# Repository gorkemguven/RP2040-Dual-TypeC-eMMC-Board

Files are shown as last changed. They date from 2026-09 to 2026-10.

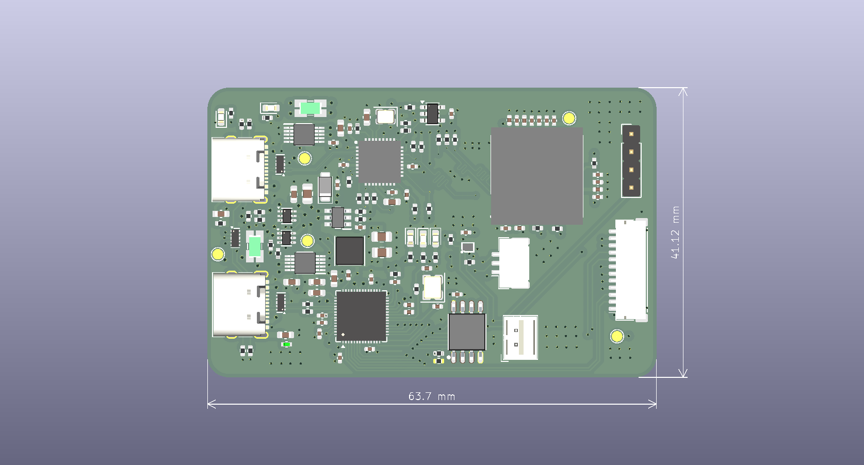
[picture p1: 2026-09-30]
KiCad Advanced Design a smart USB thumb drive_.png

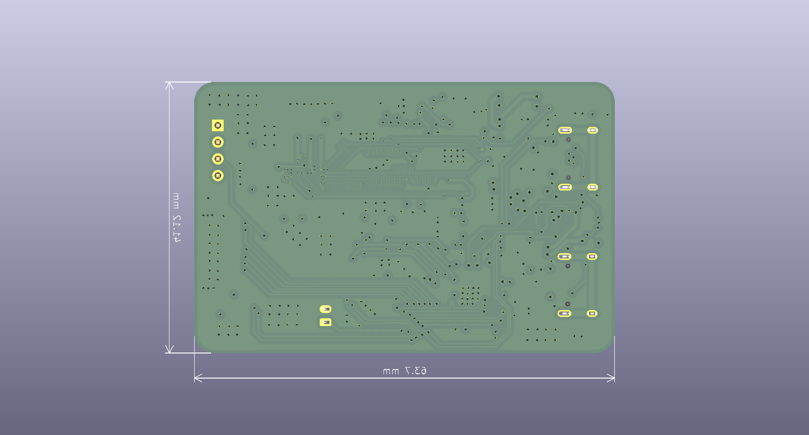
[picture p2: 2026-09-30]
KiCad Advanced Design a smart USB thumb drive.png

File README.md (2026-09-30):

# RP2040 Dual Type-C eMMC High-Speed Development & Telemetry Board (PicoVault)

Bu proje; **Raspberry Pi RP2040** çift çekirdekli mikrodenetleyicisi, **Microchip USB2244** yüksek hızlı USB 2.0 köprüsü ve **Micron eMMC (BGA-153)** yüksek yoğunluklu depolama birimini tek bir 4 katmanlı PCB üzerinde birleştiren endüstriyel standartta bir akıllı veri depolama ve geliştirme kartıdır.

Kart; çift USB Type-C mimarisi, donanımsal güç telemetrisi (çift INA226 akım/voltaj monitörü ve Kelvin algılama), yüksek doğruluklu sıcaklık izleme (TMP119) ve durum bilgilendirme OLED ekran arayüzü ile hem bağımsız bir yüksek hızlı USB flash sürücü hem de derinlemesine analiz yapabilen bir gömülü geliştirme platformu olarak tasarlanmıştır.

---

## 📌 Öne Çıkan Özellikler

* **Çift Çekirdekli İşlem Gücü:** Raspberry Pi RP2040 (Çift ARM Cortex-M0+ @ 133 MHz, 264 KB dahili SRAM).
* **Yüksek Hızlı Depolama (eMMC):** Micron BGA-153 paket yüksek hızlı eMMC bellek modülü.
* **Yüksek Hızlı USB Köprüsü:** Microchip USB2244 High-Speed USB 2.0 SD/eMMC kontrolcüsü (480 Mbps).
* **Boot Flash Belleği:** 128 Mb (16 MB) Winbond W25Q128JVSIC QSPI Flash[cite: 3].
* **Çift USB Type-C Portu:**
  * *Port 1 (Depolama):* USB2244 üzerinden doğrudan eMMC'ye yüksek hızlı USB 2.0 (480 Mbps) erişim.
  * *Port 2 (MCU / Telemetri):* RP2040 Full-Speed USB arayüzü (veri kaydı, programlama, seri haberleşme).
* **Donanımsal Güç ve Sıcaklık Telemetrisi:**
  * 2x **TI INA226** I2C güç/gerilim/akım izleme entegresi (2 mΩ 4-terminalli Kelvin şönt algılama)[cite: 7, 8].
  * 1x **TI TMP119** ±0.1°C yüksek hassasiyetli dijital sıcaklık sensörü[cite: 4].
  * 0.96'' I2C SSD1306 OLED ekran konnektörü ile anlık telemetri gösterimi[cite: 5].
* **Genişleme Portu:** Harici SPI, I2C, UART ve GPIO erişimi sağlayan 12-pin breakout soketi[cite: 1].
* **Üretim Optimizasyonu:** Maliyet düşürmek amacıyla tüm kritik bileşenler tek yüzeye (Single-Sided Assembly) yerleştirilmiştir.

---

## 📐 Donanım Mimarisi ve Yüksek Hızlı Sinyal Bütünlüğü

### 1. USB2244 – eMMC (BGA-153) 8-Bit Yüksek Hızlı Veri Yolu (Zero-Skew Matching)
USB2244 ile eMMC arasındaki 8-bit paralel veri yolu (MMC standardı), yüksek frekanslı çalışma modlarında saat ve veri gecikmelerini (skew) sıfırlamak için **tam 35.66 mm** boyuna meander teknikleriyle kusursuz şekilde eşitlenmiştir:
* **Tüm Hatların Uzunluğu:** Tam olarak **35.66 mm**
* **Maksimum Skew / Sapma:** **0.00 mm (0.00 ps)**
* **Hat Empedansı:** Katman 2 kesintisiz GND referansı üzerinden 50 Ω mikroşerit geometri.

| Sinyal Adı | Pin Adı | Rotalama Türü | Empedans | Net Hat Uzunluğu | Skew (Fark) |
| :--- | :--- | :--- | :---: | :---: | :---: |
| **`MMC_CLK`** | Clock (Saat) | GND Referanslı Mikroşerit | 50 Ω | **35.66 mm** | Referans |
| **`MMC_CMD`** | Command / Response | Çift Yönlü Kontrol | 50 Ω | **33.44 mm** | **2.22 mm** |
| **`MMCDA0`** | Data Bit 0 | Yüksek Hızlı Veri | 50 Ω | **35.66 mm** | **0.00 mm** |
| **`MMCDA1`** | Data Bit 1 | Yüksek Hızlı Veri | 50 Ω | **35.66 mm** | **0.00 mm** |
| **`MMCDA2`** | Data Bit 2 | Yüksek Hızlı Veri | 50 Ω | **35.66 mm** | **0.00 mm** |
| **`MMCDA3`** | Data Bit 3 | Yüksek Hızlı Veri | 50 Ω | **35.66 mm** | **0.00 mm** |
| **`MMCDA4`** | Data Bit 4 | Yüksek Hızlı Veri | 50 Ω | **35.56 mm** | **0.10 mm** |
| **`MMCDA5`** | Data Bit 5 | Yüksek Hızlı Veri | 50 Ω | **35.66 mm** | **0.00 mm** |
| **`MMCDA6`** | Data Bit 6 | Yüksek Hızlı Veri | 50 Ω | **35.66 mm** | **0.00 mm** |
| **`MMCDA7`** | Data Bit 7 | Yüksek Hızlı Veri | 50 Ω | **35.66 mm** | **0.00 mm** |
| **`MMC_RST_N`** | Hardware Reset | Filtrelenmiş Kontrol | 50 Ω | Bağımsız | Asenkron |

*(Not: Bu 10 hattın tamamında sıfır kör hat (stub-free) prensibi uygulanmış ve BGA çıkışlarında dönüş akımının bütünlüğü korunmuştur).*

### 2. QSPI Flash Yönlendirme ve Gecikme Eşleme (Length Matching)
Flash bellek yolu, 133 MHz saat hızında okuma/yazma kararlılığını garanti altına almak için 50 Ω kontrollü empedans ve katı boy eşleme kurallarıyla yönlendirilmiştir:
* **Tüm Sinyal Hatları:** Eşit parazitik yük için tam olarak **2 via** kullanılarak alt katmana geçirilmiştir.
* **Saat Hattı Referansı (`QSPI_SCLK`):** 24.54 mm
* **Veri Hatları Skew Dengesi:**
  * `QSPI_SD0`: 26.10 mm (ΔL = +1.56 mm)
  * `QSPI_SD1`: 25.76 mm (ΔL = +1.22 mm)
  * `QSPI_SD2`: 27.14 mm (ΔL = +2.60 mm)
  * `QSPI_SD3`: 24.81 mm (ΔL = +0.27 mm)
  * `QSPI_SS`: 22.57 mm (ΔL = -1.97 mm)
* **Stub İzolasyonu:** 1 kΩ (`R504`) BOOTSEL izolasyon direnci ve 10 kΩ (`R505`) pull-up direnci, yüksek hızlı `/CS` hattında açık devre yansıması oluşturmaması için doğrudan Flash entegresinin Pin 1 bacağının 1 mm yakınına konumlandırılmıştır[cite: 3].

### 3. Analog Kristal Osilatör Bölgesi (EMC & Noise Immunity)
* **Rezonatör:** RP2040 için 12 MHz SMD kristal ve 15 pF yük kapasitörleri.
* **Sönümleme:** `XOUT` bacağında 1 kΩ seri akım sınırlama/sönümleme direnci.
* **Gürültü Koruması (Keepout Area):** Kristalin ve yük kapasitörlerinin altındaki tüm katmanlar dijital sinyallerden arındırılmıştır[cite: 2]. `SPI_SCK` ve hızlı GPIO hatları kristal sınırının dışına taşınmış; Layer 2 üzerinde kesintisiz katı GND bakırı ve kristal gövde pinlerinde (Pin 2 ve 4) çift via topraklaması uygulanmıştır[cite: 2].

### 4. eMMC Güç Dağıtım Ağı (PDN - Decoupling Network)
* Tek yüzeyli montaj gereği dekuplaj kapasitörleri BGA-153 paketinin çevresine optimize mesafelerle dizilmiştir:
  * **VDDIM (`C2`):** 4.6 mm hat, 2 via, 100 nF + 1 µF çift filtreleme.
  * **VCC (`E6, F5` & `J10, K9`):** 100 nF, 1 µF ve 2.2 µF kapasitör grupları (6.5–8.0 mm).
  * **VCCQ (`C6` & `M4, N4, P3, P5`):** Çekirdek VCC hattındaki anahtarlama gürültüsünden etkilenmemesi için yüzeyde VCC'den izole edilmiş; ana +3.3V düzleminden yerel 2.2 µF kapasitörlerle beslenmiştir.

### 5. Kelvin Akım Algılama ve I2C Topolojisi
* **4-Wire Kelvin Sensing:** 2 mΩ şönt dirençlerin gerilim algılama pinleri (`IN+` ve `IN-`), yüksek akım taşıyan güç pedlerinden bağımsız olarak alt katmandan diferansiyel çift mantığıyla INA226 entegrelerine taşınmıştır[cite: 7, 9].
* **Adresleme:**
  * `IC702` (INA226 #1): A1 = GND, A0 = GND → **0x40**[cite: 8]
  * `IC703` (INA226 #2): A1 = GND, A0 = +3.3V → **0x41**[cite: 8]
* **I2C Veriyolu:** RP2040'tan çıkan tek veriyolu TMP119 (3.5 cm), OLED (5.3 cm), INA1 (7.0 cm) ve INA2 (8.8 cm) arayüzlerini beslemektedir[cite: 4, 5, 8]. Hat empedansı TMP119 yakınındaki 5 kΩ pull-up dirençleri (`R701`, `R702`) ile sürülmekte ve toplam veriyolu kapasitansı 400 pF standardının oldukça altında kalmaktadır[cite: 4, 6].

---

## 🔌 Bağlantı Portları ve Pin Şeması

### 1. J803 Genişleme Konnektörü (1x12 Pin Header)
Harici çevre birimleri ve geliştirme modülleri için dışarı çıkarılmış arayüzdür[cite: 1]:

| Pin | Sinyal Adı | Tip | Rotalama Detayı | Açıklama |
| :---: | :--- | :--- | :--- | :--- |
| **1** | `+3.3V` | Güç | Çift via ile +3.3V katmanına bağlı | Harici modül beslemesi |
| **2** | `UART_TX` | Çıkış | 50.00 mm (0 via) | Seri konsol / Debug çıkışı |
| **3** | `UART_RX` | Giriş | 49.80 mm (0 via) | Seri konsol giriş |
| **4** | `SPI_SCK` | Çıkış | 42.17 mm (2 via) | Harici SPI Saat hattı |
| **5** | `SPI_MOSI` | Çıkış | 41.52 mm (2 via) | Harici SPI Veri çıkışı |
| **6** | `SPI_MISO` | Giriş | 41.83 mm (2 via) | Harici SPI Veri girişi |
| **7** | `SPI_CS` | Çıkış | 41.92 mm (2 via) | Harici SPI Çip seçimi |
| **8** | `I2C_SDA` | Çift Yönlü | 57.08 mm (2 via) | Harici I2C Veri hattı |
| **9** | `I2C_SCL` | Çıkış | 56.62 mm (2 via) | Harici I2C Saat hattı |
| **10** | `GPIO14` | Giriş/Çıkış | 43.70 mm (2 via) | Genel amaçlı GPIO / Kesme |
| **11** | `GPIO15` | Giriş/Çıkış | 43.87 mm (2 via) | Genel amaçlı GPIO / Kesme |
| **12** | `GND` | Güç | Çift via ile ana GND katmanına bağlı | Ortak sistem toprağı |

*(Not: SPI veri yolu hatları arasındaki maksimum skew yalnızca 0.65 mm'dir; bu sayede yüksek hızlı SPI ekranlar veya harici modüllerle sorunsuz çalışır).*

### 2. Programlama ve Hata Ayıklama (Debug)
* **SWD Portu (`SWCLK`, `SWD`, `GND`):** Canlı hata ayıklama (step-by-step breakpoint debug) ve doğrudan bellek programlama arayüzüdür.
  * `SWCLK` (22.60 mm) ve `SWD` (23.00 mm) hatları tam simetrik ve 0.40 mm toleransla eşlenmiştir.
* **RUN (Donanımsal Reset):** 100 nF kapasitör ve 10 kΩ pull-up direnci ile çipin 3.66 mm dibinde filtrelenmiştir.
* **J502 (`USB_BOOT`):** 1 kΩ direnç üzerinden Flash `/CS` hattını toprağa çekerek RP2040'ı dahili ROM UF2 Mass Storage bootloader moduna geçirir[cite: 3].

---

## 🗂️ Depo Dosya Yapısı

```text
├── hardware/
│   ├── schematics/          # KiCad hiyerarşik şematik dosyaları (.kicad_sch)
│   ├── layout/              # KiCad 4-katman PCB yerleşim dosyaları (.kicad_pcb)
│   ├── libraries/           # Projeye özel kütüphane sembol ve ayak izleri (Footprints)
│   └── outputs/
│       ├── gerbers/         # Üretim için RS-274X Gerber ve Drill dosyaları
│       └── bom/             # Parça listesi (Bill of Materials - .csv)
├── docs/
│   ├── schematics.pdf       # Tek tıkla incelenebilir tam şematik PDF çıktısı
│   ├── 3d_renders/          # Kartın ön/arka 3D görsel renderları
│   └── datasheets/          # Kritik entegre dökümanları (USB2244, INA226, TMP119, W25Q128)
├── .gitignore               # KiCad geçici ve yedek dosyalarını filtreler
└── README.md                # Proje dokümantasyonu

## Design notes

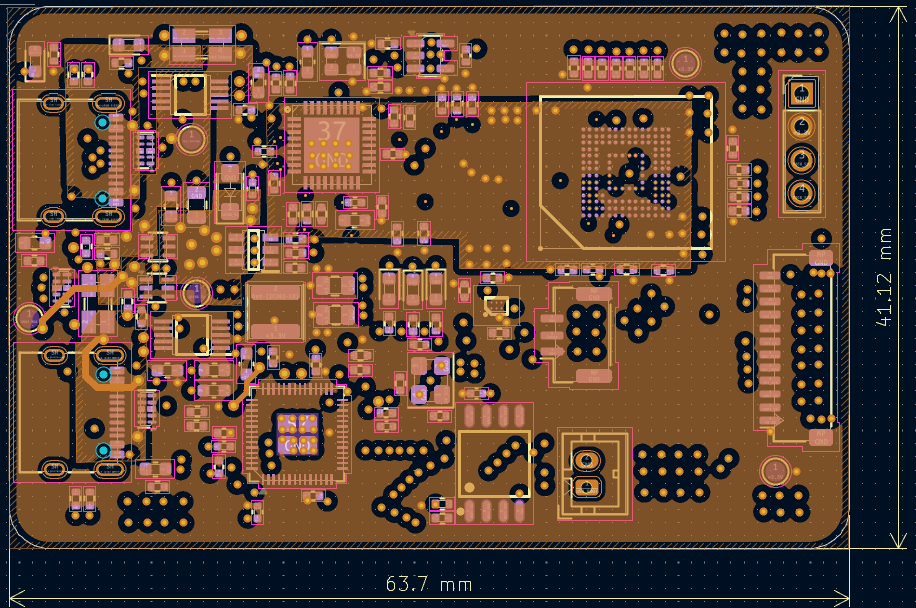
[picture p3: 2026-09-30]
akıllı_usb_bellek_layer_3.png

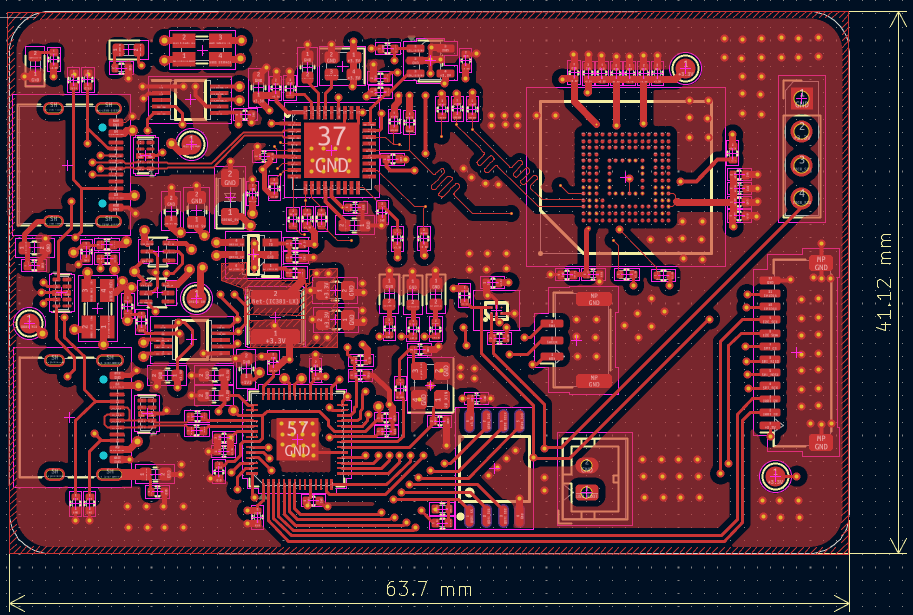
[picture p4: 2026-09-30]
akıllı_usb_bellek_layer_1.png

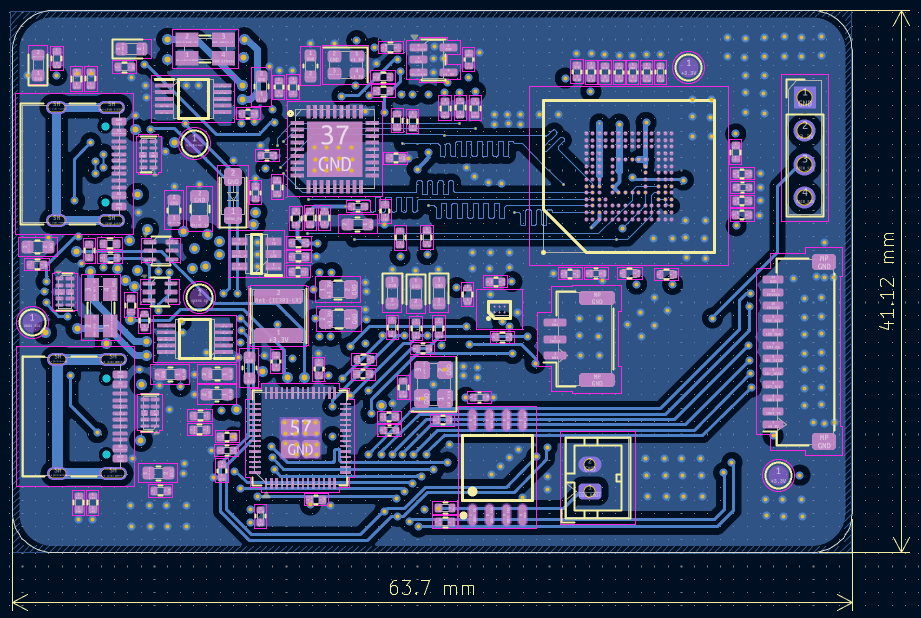
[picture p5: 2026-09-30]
akıllı_usb_bellek_layer_4.png

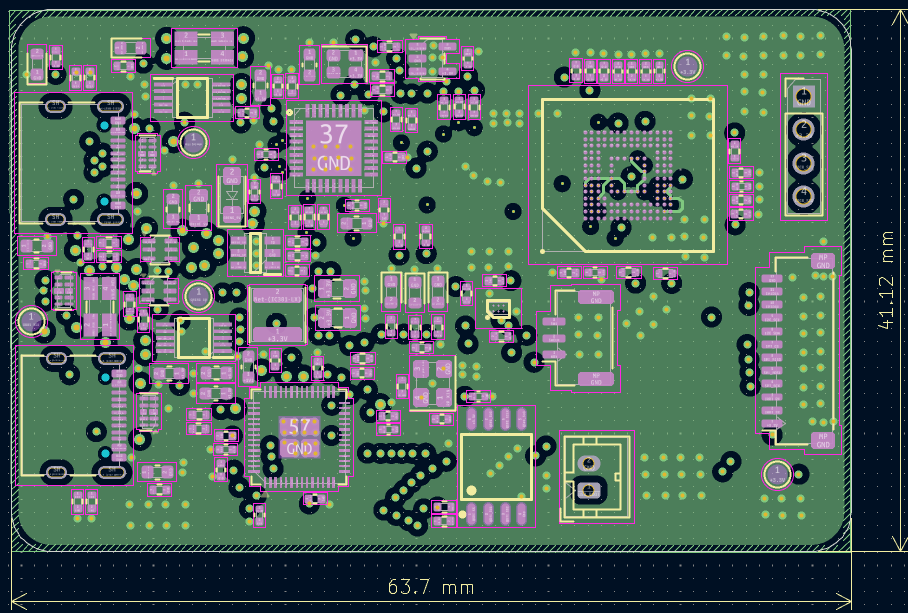
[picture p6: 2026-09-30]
akıllı_usb_bellek_layer_2.png

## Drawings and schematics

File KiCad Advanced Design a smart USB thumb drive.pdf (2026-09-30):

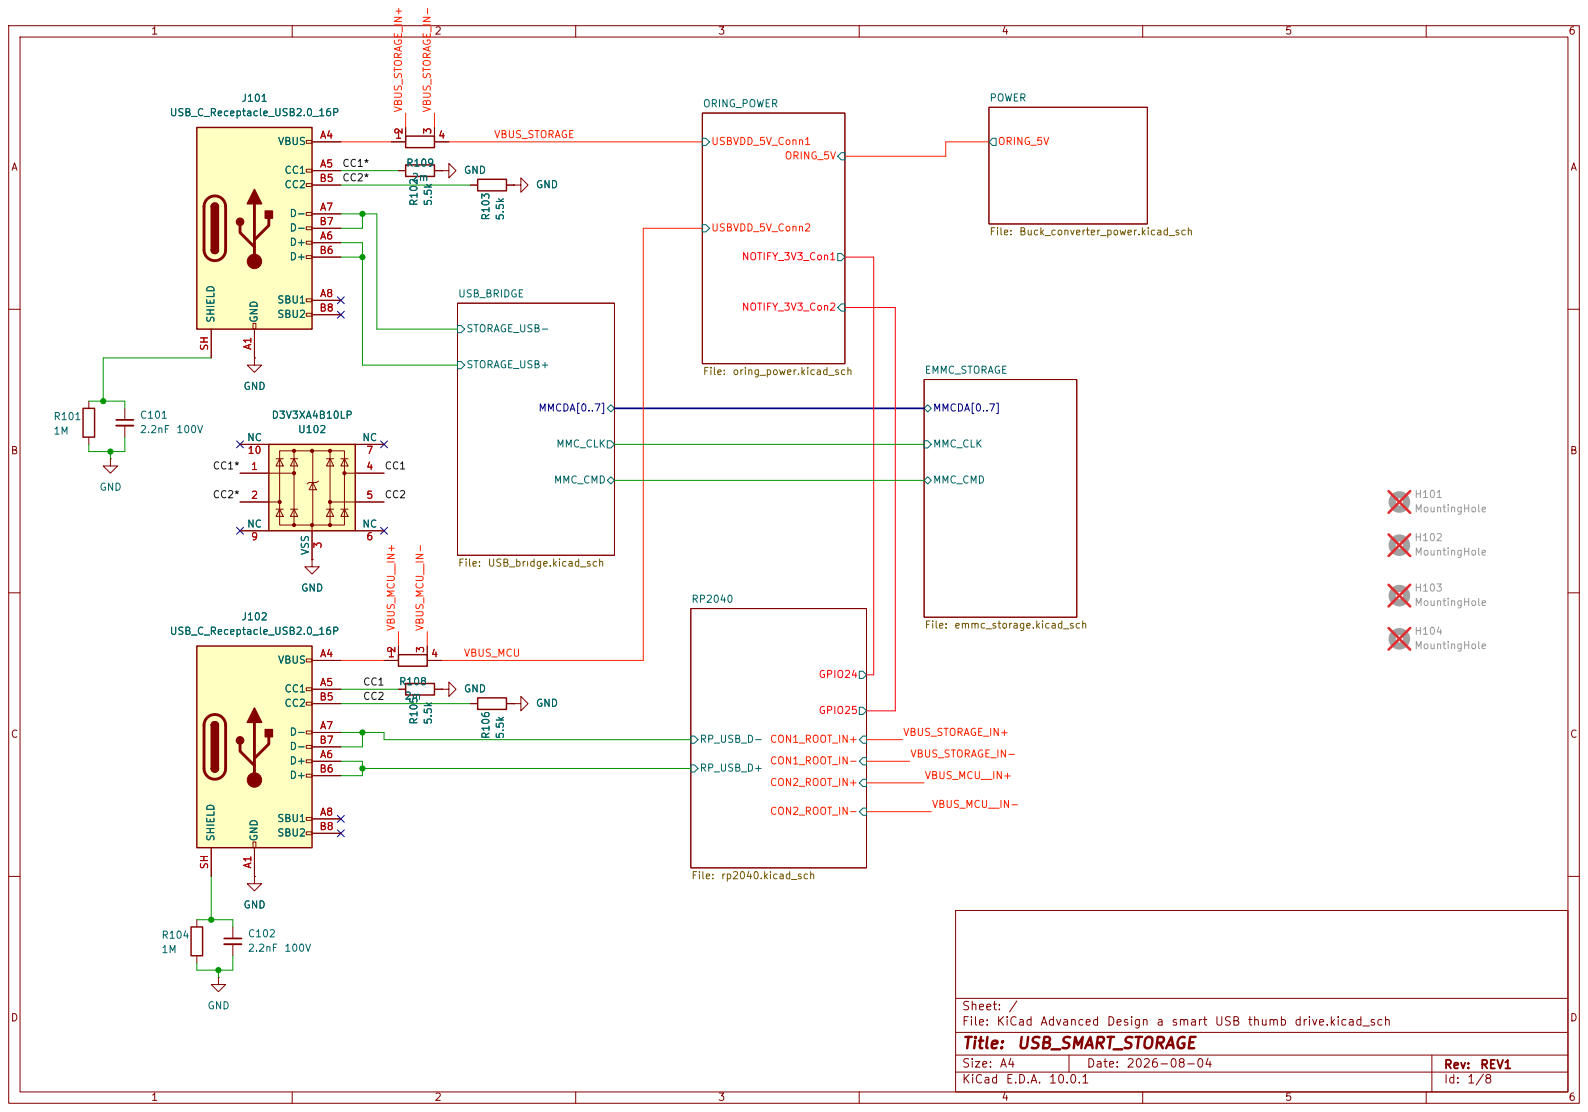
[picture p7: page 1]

Sheet: /
File: KiCad Advanced Design a smart USB thumb drive.kicad_sch
Title: USB_SMART_STORAGE

Size: A4 | Rev: REV1
KiCad E.D.A. 10.0.1 | Id: 1/8

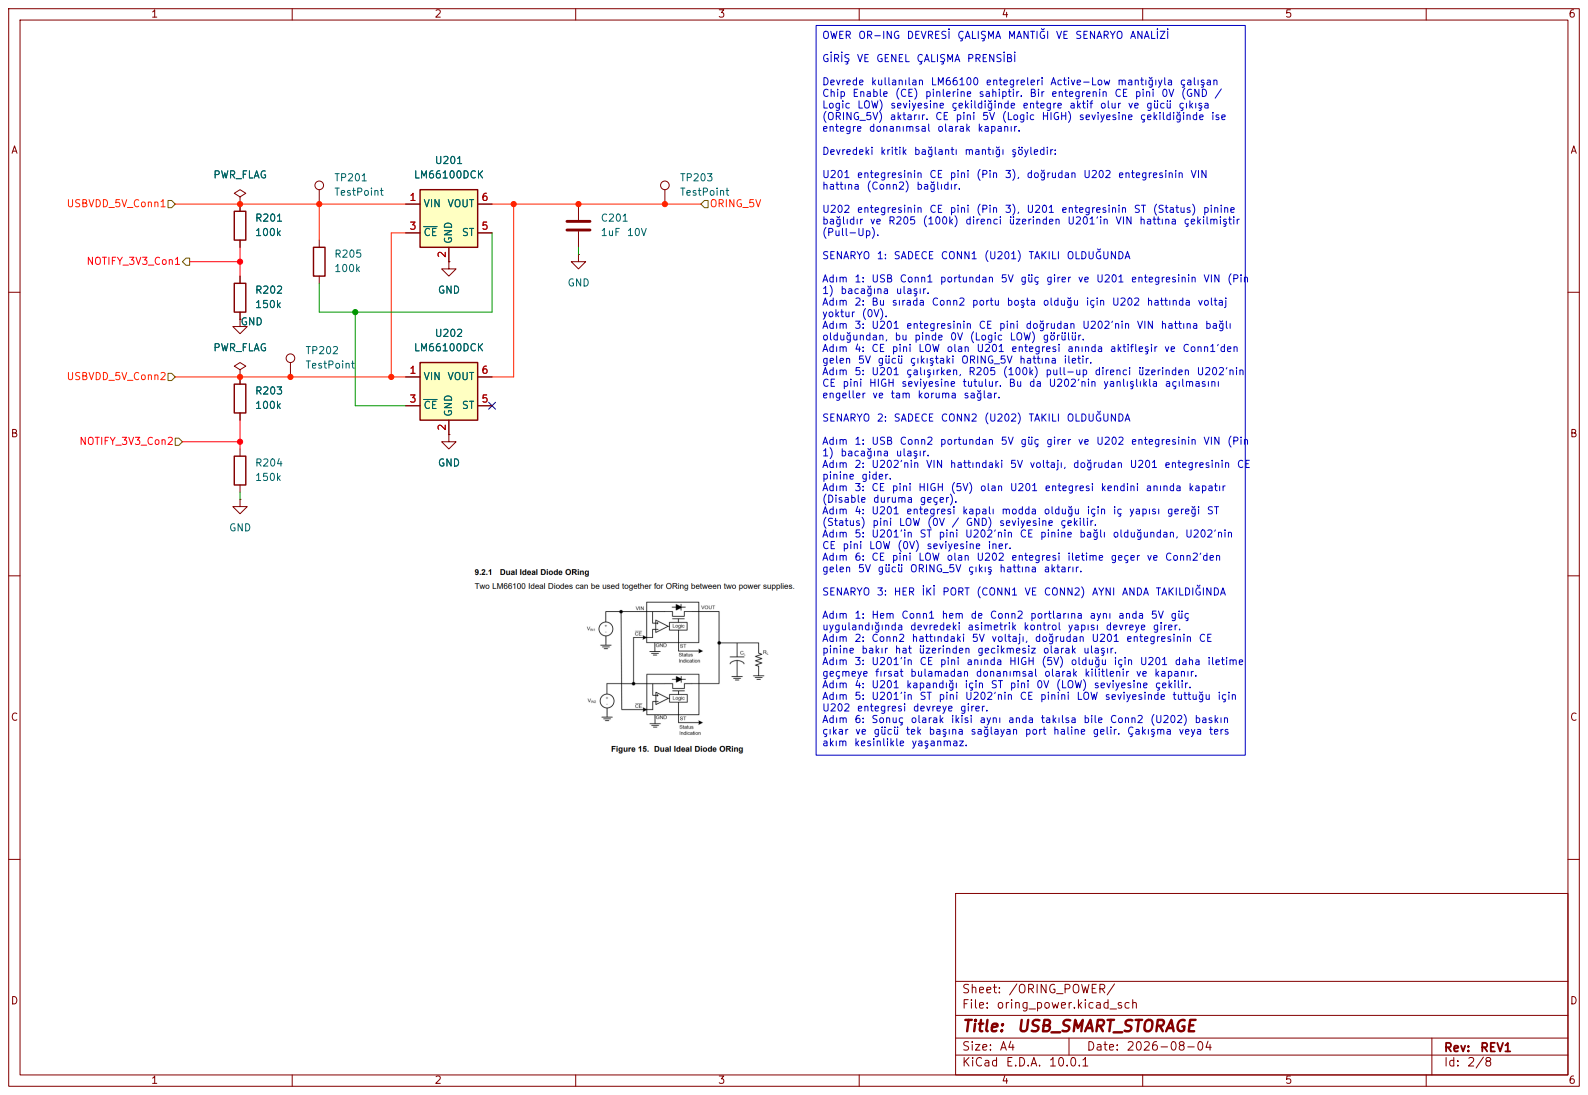
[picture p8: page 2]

GİRİŞ VE GENEL ÇALIŞMA PRENSİBİ Devrede kullanılan LM66100 entegreleri Active-Low mantığıyla çalışan

Chip Enable (CE) pinlerine sahiptir. Bir entegrenin CE pini 0V (GND /
Logic LOW) seviyesine çekildiğinde entegre aktif olur ve gücü çıkışa
(ORING_5V) aktarır. CE pini 5V (Logic HIGH) seviyesine çekildiğinde ise
entegre donanımsal olarak kapanır. Devredeki kritik bağlantı mantığı şöyledir: U201 entegresinin CE pini (Pin 3), doğrudan U202 entegresinin VIN

hattına (Conn2) bağlıdır. U202 entegresinin CE pini (Pin 3), U201 entegresinin ST (Status) pinine

bağlıdır ve R205 (100k) direnci üzerinden U201'in VIN hattına çekilmiştir
(Pull-Up). SENARYO 1: SADECE CONN1 (U201) TAKILI OLDUĞUNDA

Adım 1: USB Conn1 portundan 5V güç girer ve U201 entegresinin VIN (Pin 1) bacağına ulaşır. Adım 2: Bu sırada Conn2 portu boşta olduğu için U202 hattında voltaj

yoktur (0V). Adım 3: U201 entegresinin CE pini doğrudan U202'nin VIN hattına bağlı

olduğundan, bu pinde 0V (Logic LOW) görülür. Adım 4: CE pini LOW olan U201 entegresi anında aktifleşir ve Conn1'den

gelen 5V gücü çıkıştaki ORING_5V hattına iletir. Adım 5: U201 çalışırken, R205 (100k) pull-up direnci üzerinden U202'nin CE pini HIGH seviyesine tutulur. Bu da U202'nin yanlışlıkla açılmasını

engeller ve tam koruma sağlar. SENARYO 2: SADECE CONN2 (U202) TAKILI OLDUĞUNDA

Adım 1: USB Conn2 portundan 5V güç girer ve U202 entegresinin VIN (Pin 1) bacağına ulaşır. Adım 2: U202'nin VIN hattındaki 5V voltajı, doğrudan U201 entegresinin CE

pinine gider. Adım 3: CE pini HIGH (5V) olan U201 entegresi kendini anında kapatır

(Disable duruma geçer). Adım 4: U201 entegresi kapalı modda olduğu için iç yapısı gereği ST

(Status) pini LOW (0V / GND) seviyesine çekilir. Adım 5: U201'in ST pini U202'nin CE pinine bağlı olduğundan, U202'nin CE pini LOW (0V) seviyesine iner. Adım 6: CE pini LOW olan U202 entegresi iletime geçer ve Conn2'den

gelen 5V gücü ORING_5V çıkış hattına aktarır. SENARYO 3: HER İKİ PORT (CONN1 VE CONN2) AYNI ANDA TAKILDIĞINDA

Adım 1: Hem Conn1 hem de Conn2 portlarına aynı anda 5V güç
uygulandığında devredeki asimetrik kontrol yapısı devreye girer. Adım 2: Conn2 hattındaki 5V voltajı, doğrudan U201 entegresinin CE

pinine bakır hat üzerinden gecikmesiz olarak ulaşır. Adım 3: U201'in CE pini anında HIGH (5V) olduğu için U201 daha iletime geçmeye fırsat bulamadan donanımsal olarak kilitlenir ve kapanır. Adım 4: U201 kapandığı için ST pini 0V (LOW) seviyesine çekilir. Adım 5: U201'in ST pini U202'nin CE pinini LOW seviyesinde tuttuğu için U202 entegresi devreye girer. Adım 6: Sonuç olarak ikisi aynı anda takılsa bile Conn2 (U202) baskın

çıkar ve gücü tek başına sağlayan port haline gelir. Çakışma veya ters akım kesinlikle yaşanmaz.

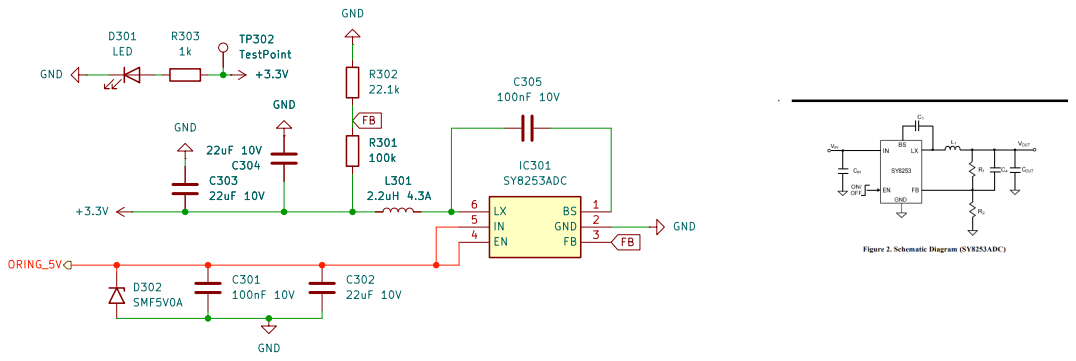
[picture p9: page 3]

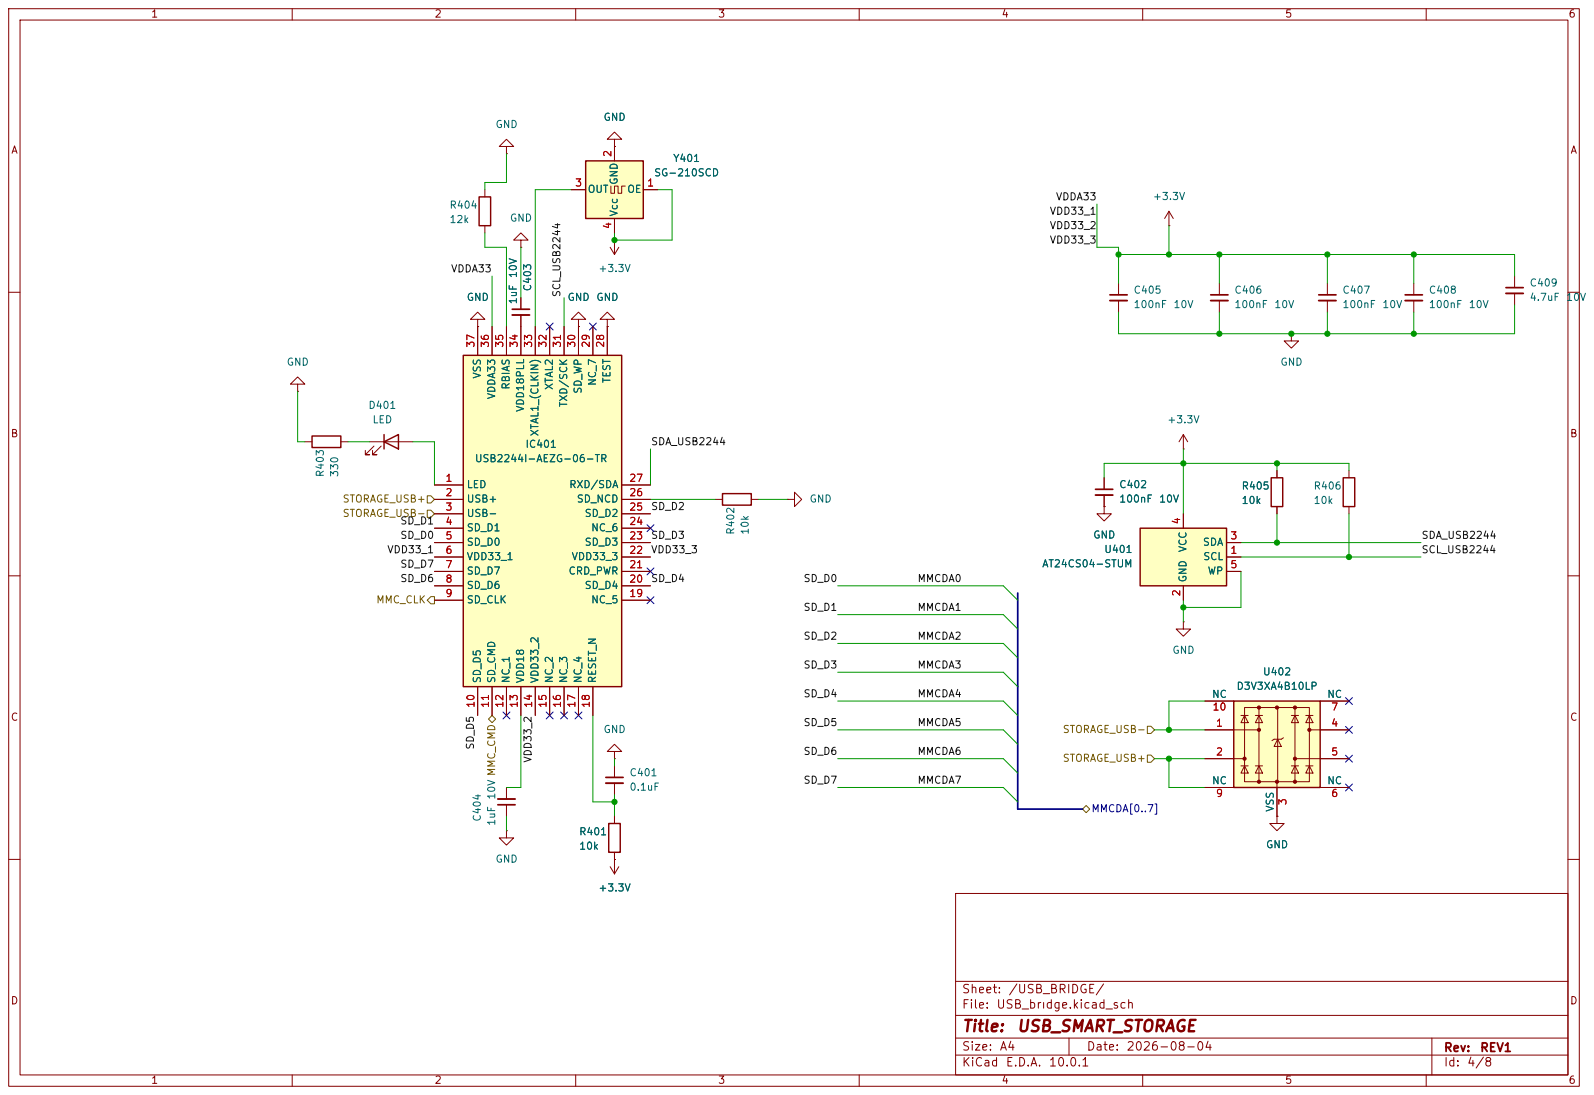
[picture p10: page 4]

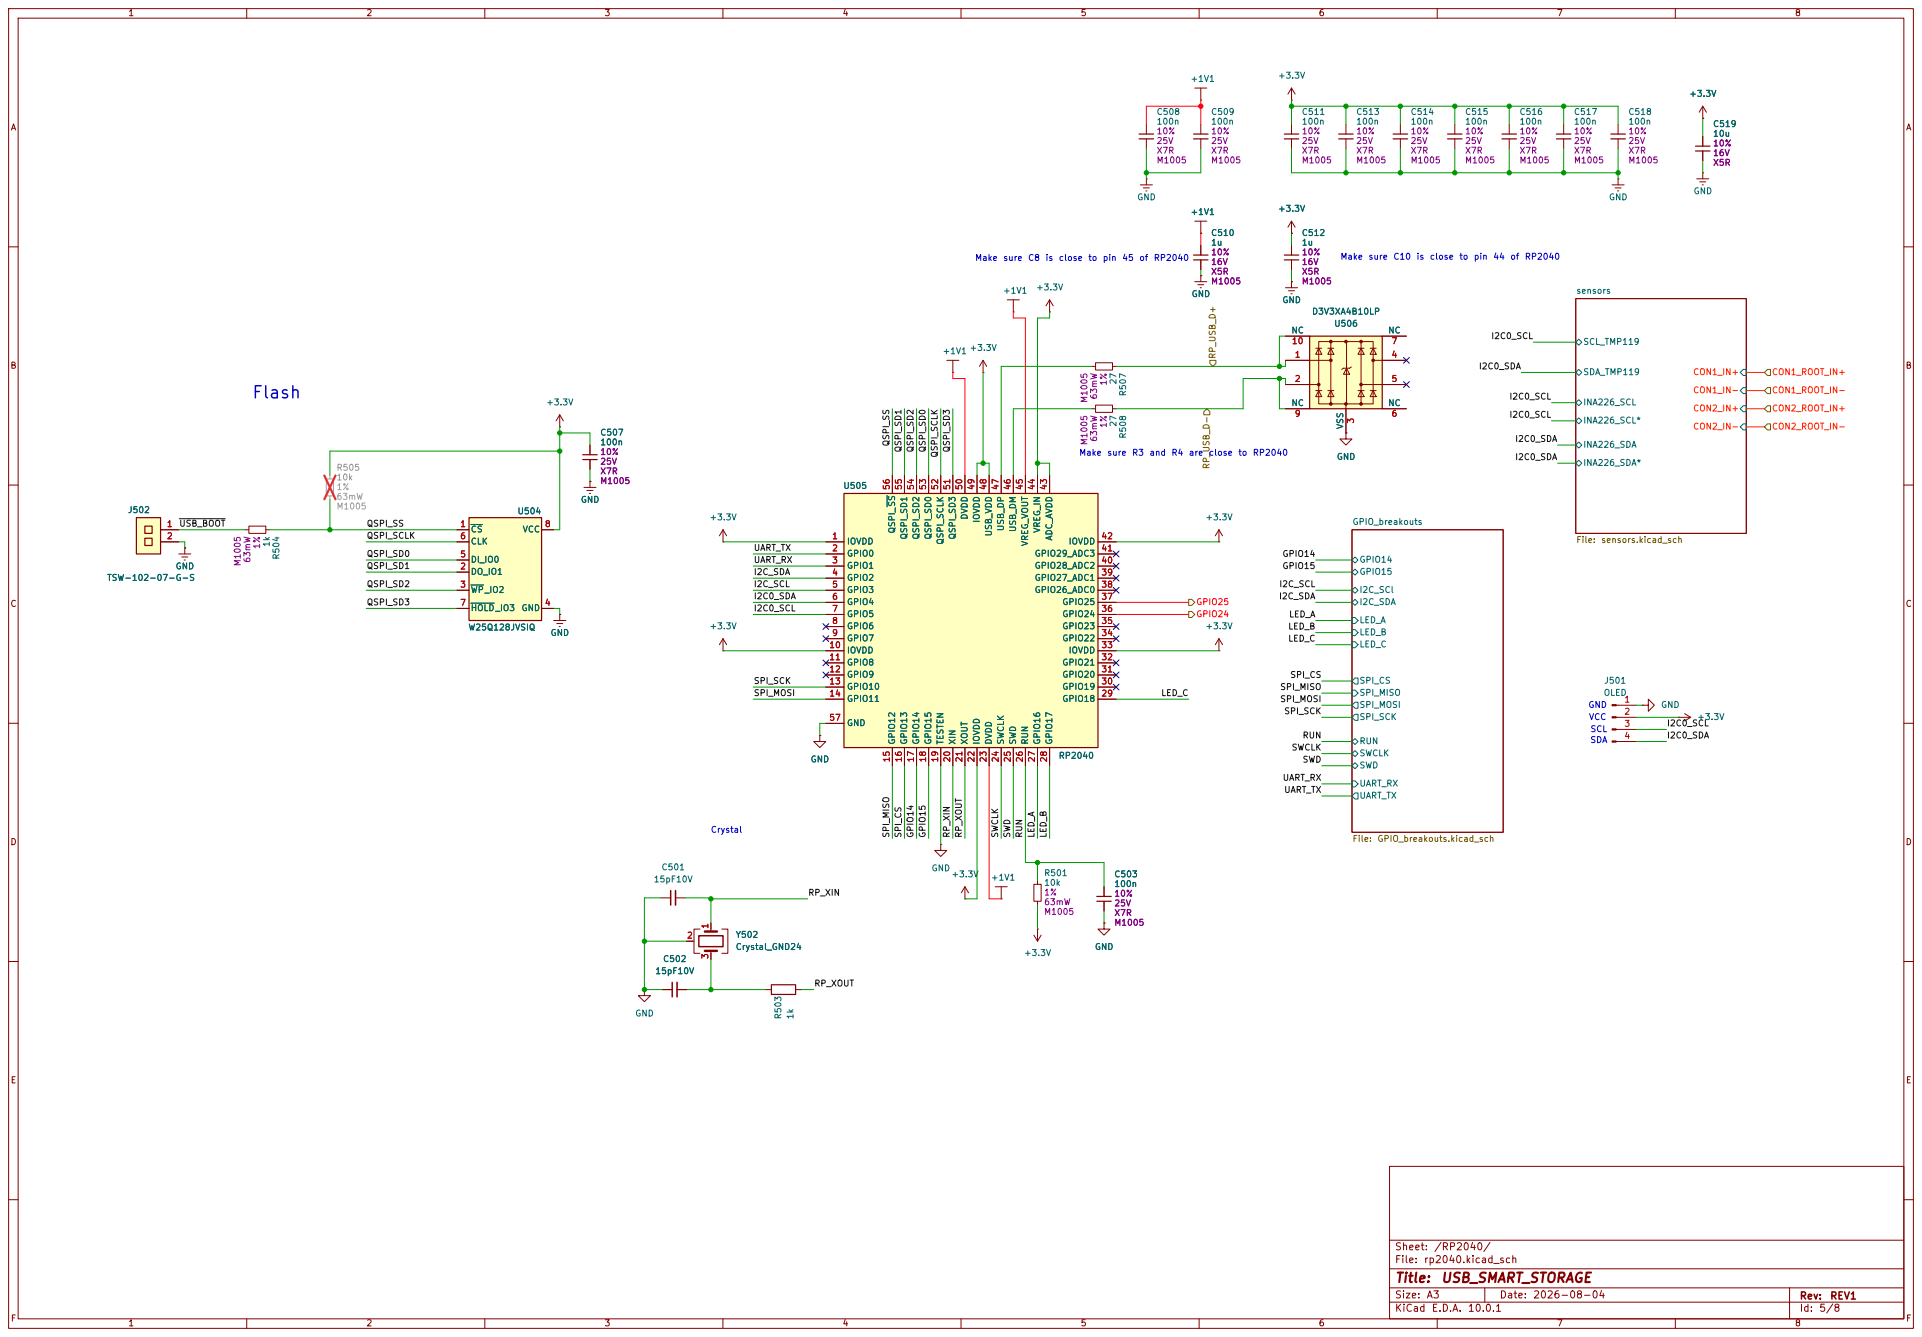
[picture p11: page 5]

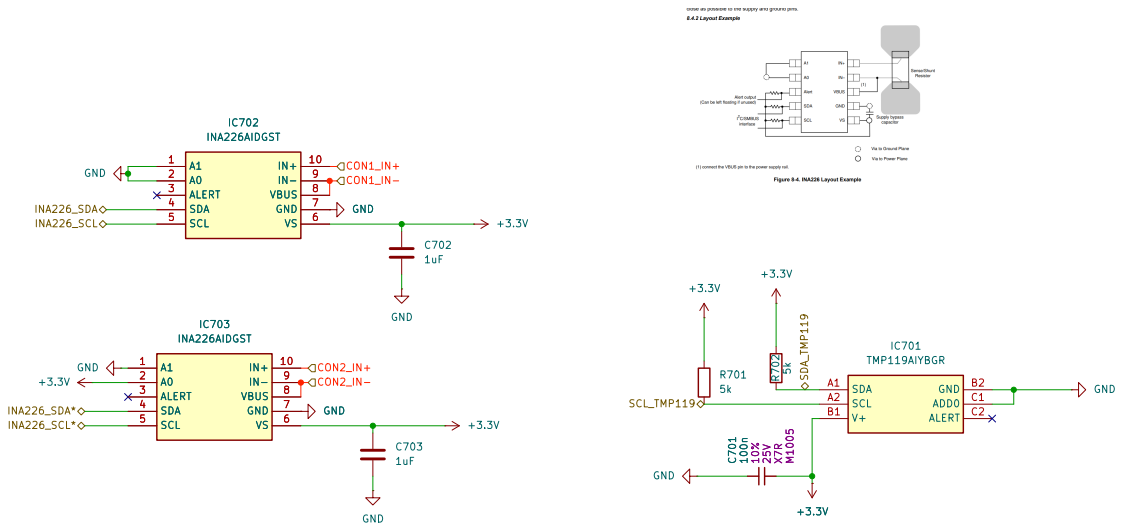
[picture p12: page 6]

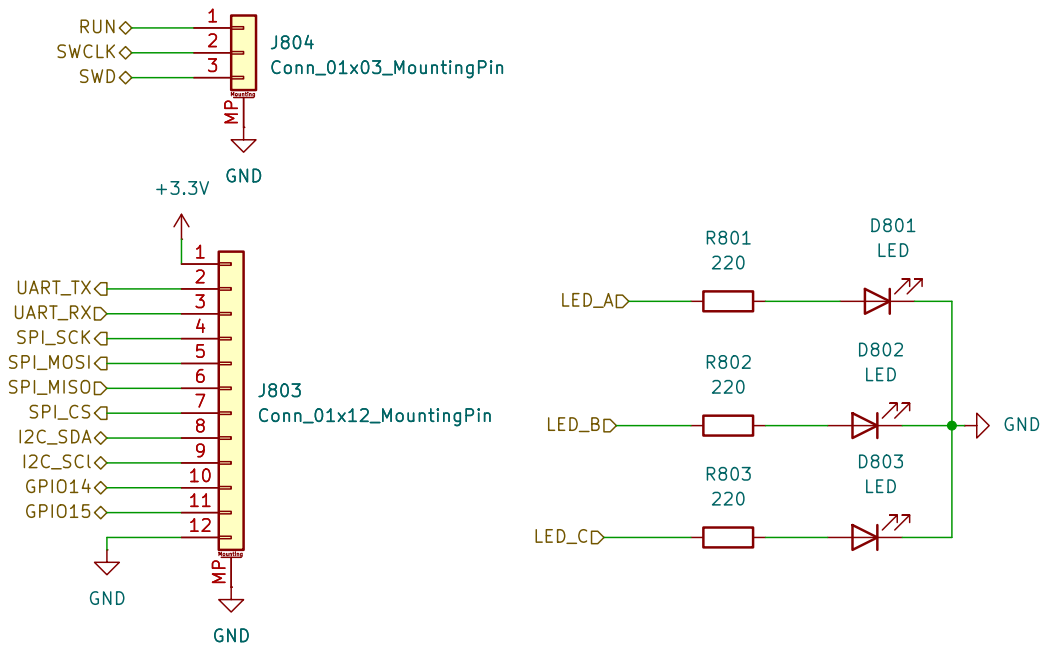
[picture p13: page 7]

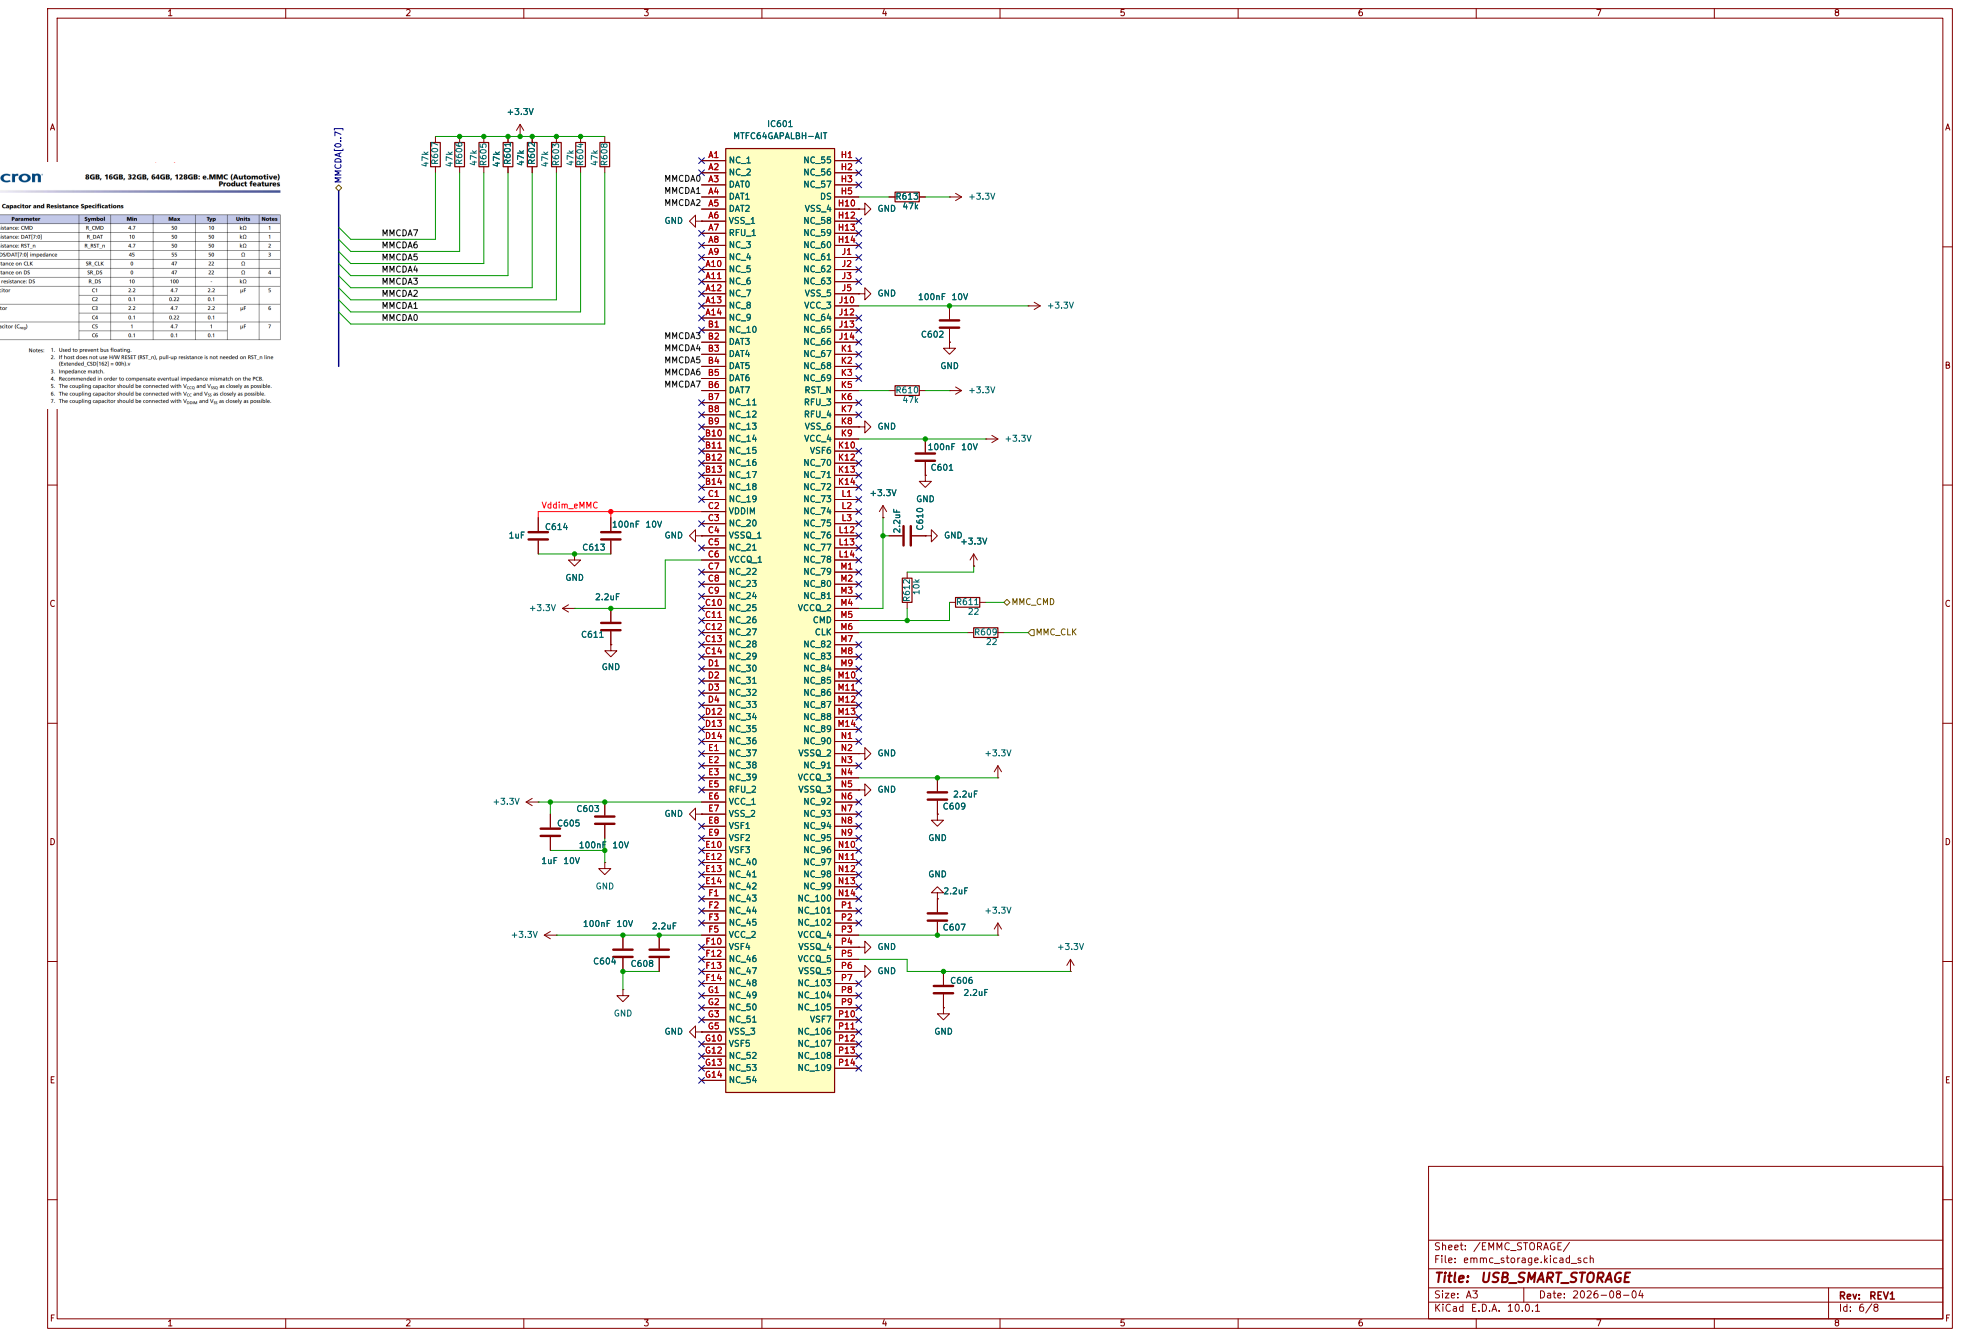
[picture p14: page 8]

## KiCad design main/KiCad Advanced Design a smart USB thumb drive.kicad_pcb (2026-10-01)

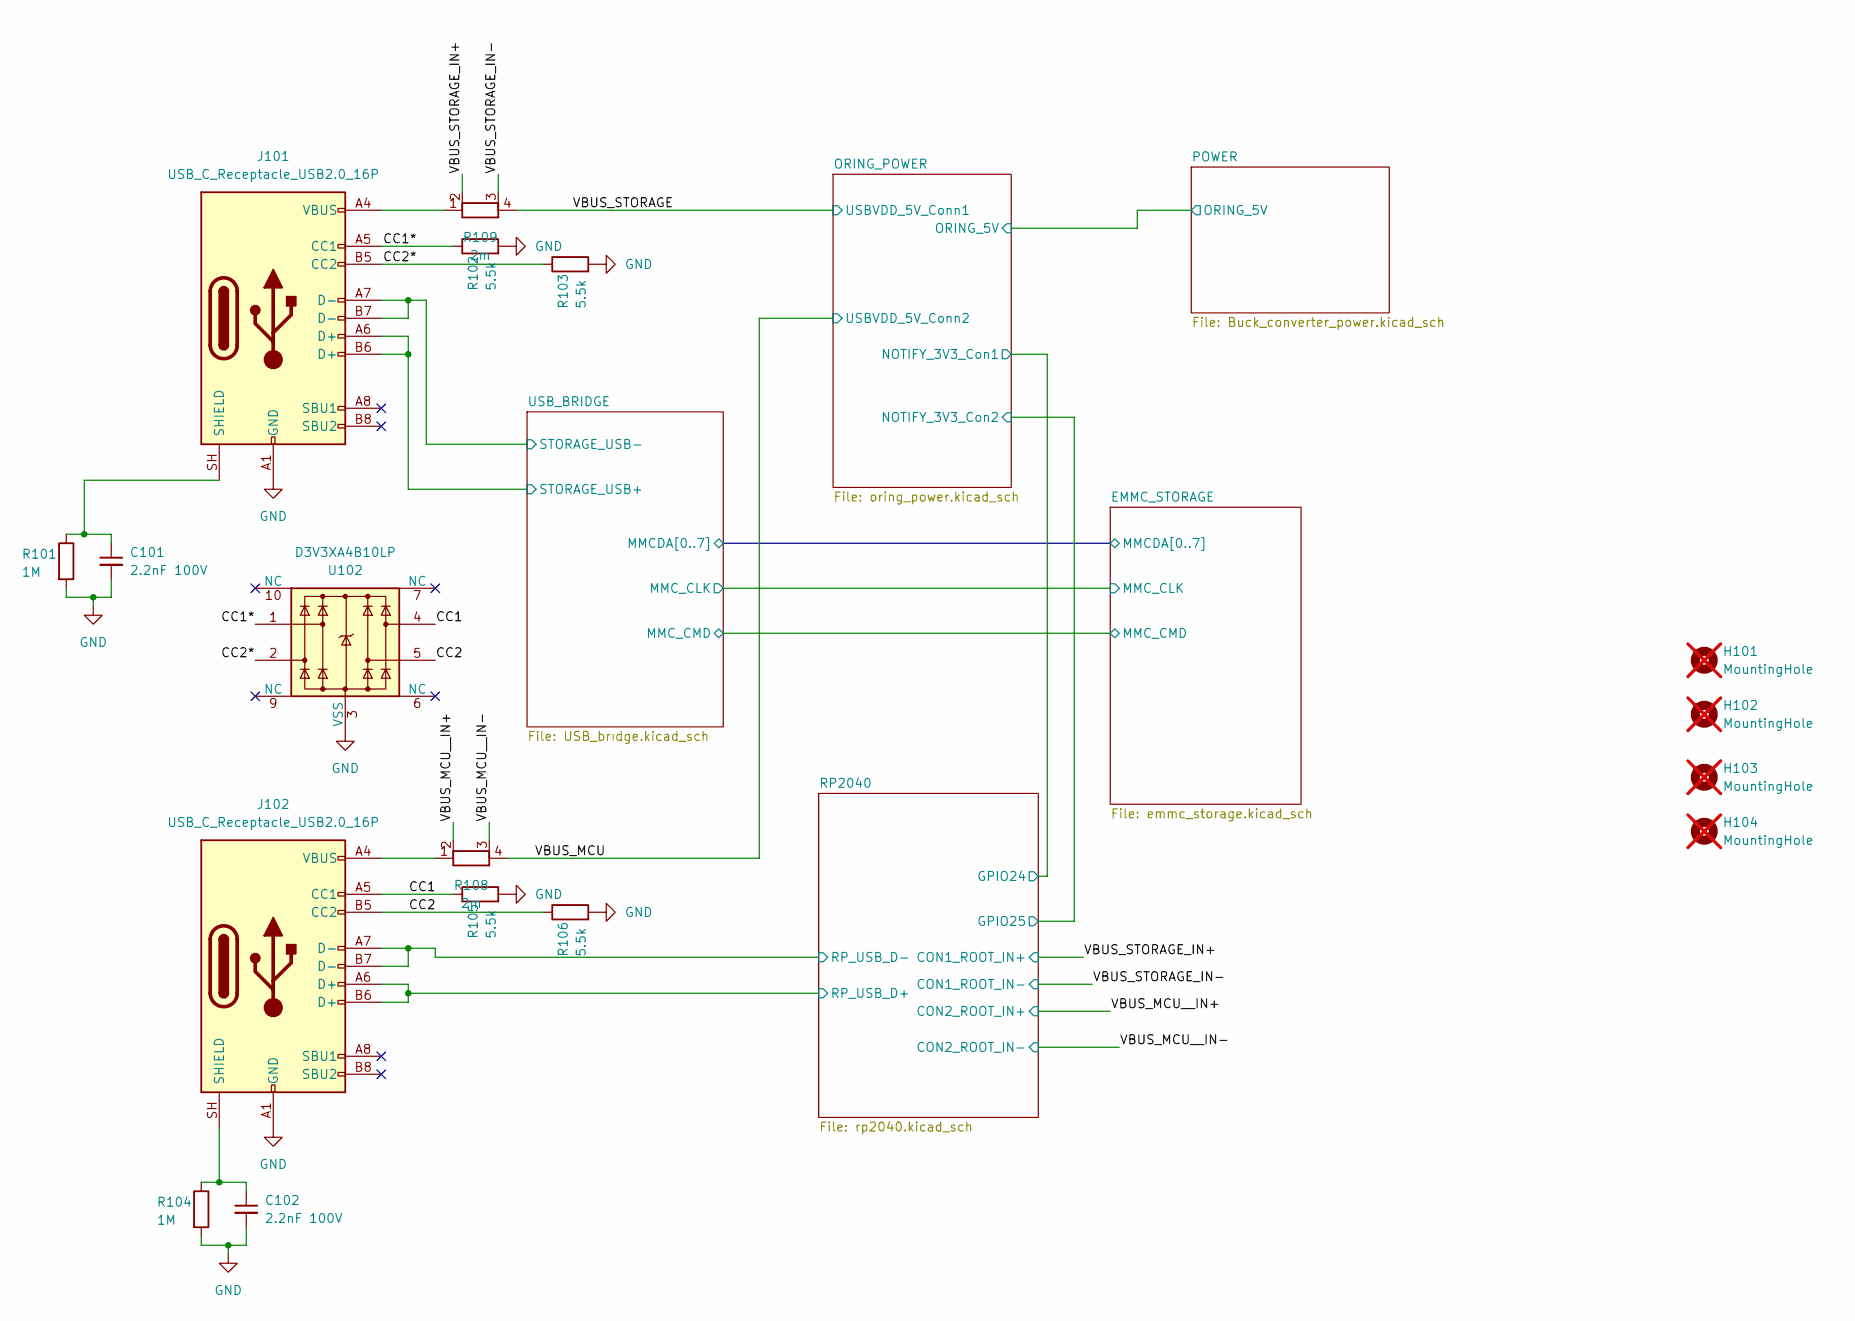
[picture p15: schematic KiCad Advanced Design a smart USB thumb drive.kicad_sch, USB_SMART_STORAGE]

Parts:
C101, C102: 2.2nF 100V; C_0603_1608Metric
H101, H102, H103, H104: MountingHole; MountingHole_2.2mm_M2; not fitted
J101, J102: USB_C_Receptacle_USB2.0_16P; USB_C_Receptacle_XKB_U262-16XN-4BVC11
R101, R104: 1M; R_0402_1005Metric
R102, R103, R105, R106: 5.5k; R_0402_1005Metric
R108, R109: 2m; R_Shunt_Ohmite_LVK12
U102: D3V3XA4B10LP; Diodes_UDFN-10_1x2.5mm_P0.5mm

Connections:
/CC1: J102.A5 (CC1), R105.1, U102.4
/CC1*: J101.A5 (CC1), R102.1, U102.1
/CC2: J102.B5 (CC2), R106.1, U102.5
/CC2*: J101.B5 (CC2), R103.1, U102.2
/RP2040/RP_USB_D+: J102.A6 (D+), J102.B6 (D+); also elsewhere on the board
/RP2040/RP_USB_D-: J102.A7 (D-), J102.B7 (D-); also elsewhere on the board
/USB_BRIDGE/STORAGE_USB+: J101.A6 (D+), J101.B6 (D+); also elsewhere on the board
/USB_BRIDGE/STORAGE_USB-: J101.A7 (D-), J101.B7 (D-); also elsewhere on the board
/VBUS_MCU: R108.4; also elsewhere on the board
/VBUS_MCU__IN+: R108.2; also elsewhere on the board
/VBUS_MCU__IN-: R108.3; also elsewhere on the board
/VBUS_STORAGE: R109.4; also elsewhere on the board
/VBUS_STORAGE_IN+: R109.2; also elsewhere on the board
/VBUS_STORAGE_IN-: R109.3; also elsewhere on the board
GND: C101.2, C102.2, J101.A1 (GND), J101.A12 (GND), J101.B1 (GND), J101.B12 (GND), J102.A1 (GND), J102.A12 (GND), J102.B1 (GND), J102.B12 (GND), R101.2, R102.2, R103.2, R104.2, R105.2, R106.2, U102.3 (VSS), U102.8 (VSS); also elsewhere on the board
unnamed: C101.1, J101.SH (SHIELD), R101.1
unnamed: J101.A4 (VBUS), J101.A9 (VBUS), J101.B4 (VBUS), J101.B9 (VBUS), R109.1
unnamed: C102.1, J102.SH (SHIELD), R104.1
unnamed: J102.A4 (VBUS), J102.A9 (VBUS), J102.B4 (VBUS), J102.B9 (VBUS), R108.1

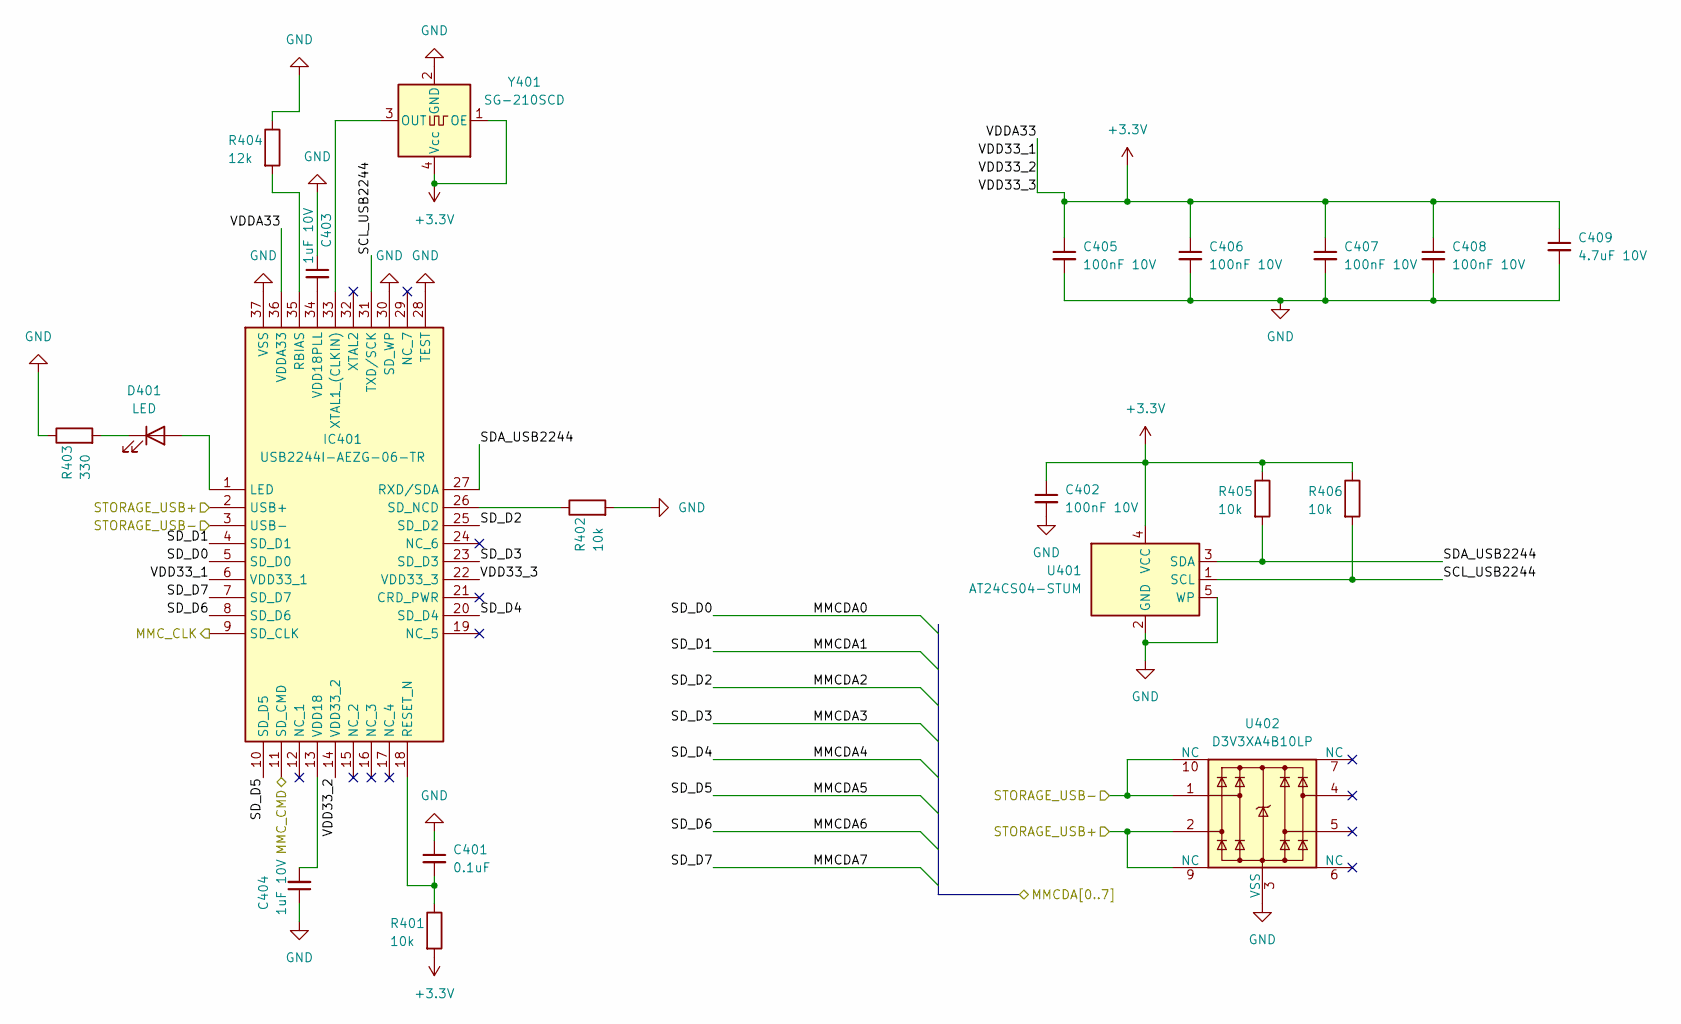
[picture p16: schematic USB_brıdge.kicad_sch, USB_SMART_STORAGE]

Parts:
C401: 0.1uF; C_0402_1005Metric
C402, C405, C406, C407, C408: 100nF 10V; C_0402_1005Metric
C403, C404: 1uF 10V; C_0603_1608Metric
C409: 4.7uF 10V; C_0603_1608Metric
D401: LED; LED_0603_1608Metric
IC401: USB2244I-AEZG-06-TR; QFN50P600X600X90-37N-D; Manufacturer_Part_Number USB2244I-AEZG-06-TR; Mouser Part Number 579-USB2244IAEZG06TR
R401, R402, R405, R406: 10k; R_0402_1005Metric
R403: 330; R_0402_1005Metric
R404: 12k; R_0402_1005Metric
U401: AT24CS04-STUM; SOT-23-5
U402: D3V3XA4B10LP; Diodes_UDFN-10_1x2.5mm_P0.5mm
Y401: SG-210SCD; Oscillator_SMD_SeikoEpson_SG210-4Pin_2.5x2.0mm

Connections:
+3.3V: C402.1, C405.1, C406.1, C407.1, C408.1, C409.1, IC401.6 (VDD33_1), IC401.14 (VDD33_2), IC401.22 (VDD33_3), IC401.36 (VDDA33), R401.2, R405.1, R406.1, U401.4 (VCC), Y401.1 (OE), Y401.4 (Vcc); also elsewhere on the board
/EMMC_STORAGE/MMCDA0: IC401.5 (SD_D0); also elsewhere on the board
/EMMC_STORAGE/MMCDA1: IC401.4 (SD_D1); also elsewhere on the board
/EMMC_STORAGE/MMCDA2: IC401.25 (SD_D2); also elsewhere on the board
/EMMC_STORAGE/MMCDA3: IC401.23 (SD_D3); also elsewhere on the board
/EMMC_STORAGE/MMCDA4: IC401.20 (SD_D4); also elsewhere on the board
/EMMC_STORAGE/MMCDA5: IC401.10 (SD_D5); also elsewhere on the board
/EMMC_STORAGE/MMCDA6: IC401.8 (SD_D6); also elsewhere on the board
/EMMC_STORAGE/MMCDA7: IC401.7 (SD_D7); also elsewhere on the board
/EMMC_STORAGE/MMC_CLK: IC401.9 (SD_CLK); also elsewhere on the board
/EMMC_STORAGE/MMC_CMD: IC401.11 (SD_CMD); also elsewhere on the board
/USB_BRIDGE/SCL_USB2244: IC401.31 (TXD/SCK), R406.2, U401.1 (SCL)
/USB_BRIDGE/SDA_USB2244: IC401.27 (RXD/SDA), R405.2, U401.3 (SDA)
/USB_BRIDGE/STORAGE_USB+: IC401.2 (USB+), U402.2, U402.9 (NC); also elsewhere on the board
/USB_BRIDGE/STORAGE_USB-: IC401.3 (USB-), U402.1, U402.10 (NC); also elsewhere on the board
GND: C401.1, C402.2, C403.1, C404.1, C405.2, C406.2, C407.2, C408.2, C409.2, IC401.28 (TEST), IC401.30 (SD_WP), IC401.37 (VSS), R402.2, R403.1, R404.1, U401.2 (GND), U401.5 (WP), U402.3 (VSS), U402.8 (VSS), Y401.2 (GND); also elsewhere on the board
unnamed: D401.2 (A), IC401.1 (LED)
unnamed: D401.1 (K), R403.2
unnamed: IC401.35 (RBIAS), R404.2
unnamed: C401.2, IC401.18 (RESET_N), R401.1
unnamed: IC401.26 (SD_NCD), R402.1
unnamed: C404.2, IC401.13 (VDD18)
unnamed: C403.2, IC401.34 (VDD18PLL)
unnamed: IC401.33 (XTAL1_(CLKIN)), Y401.3 (OUT)

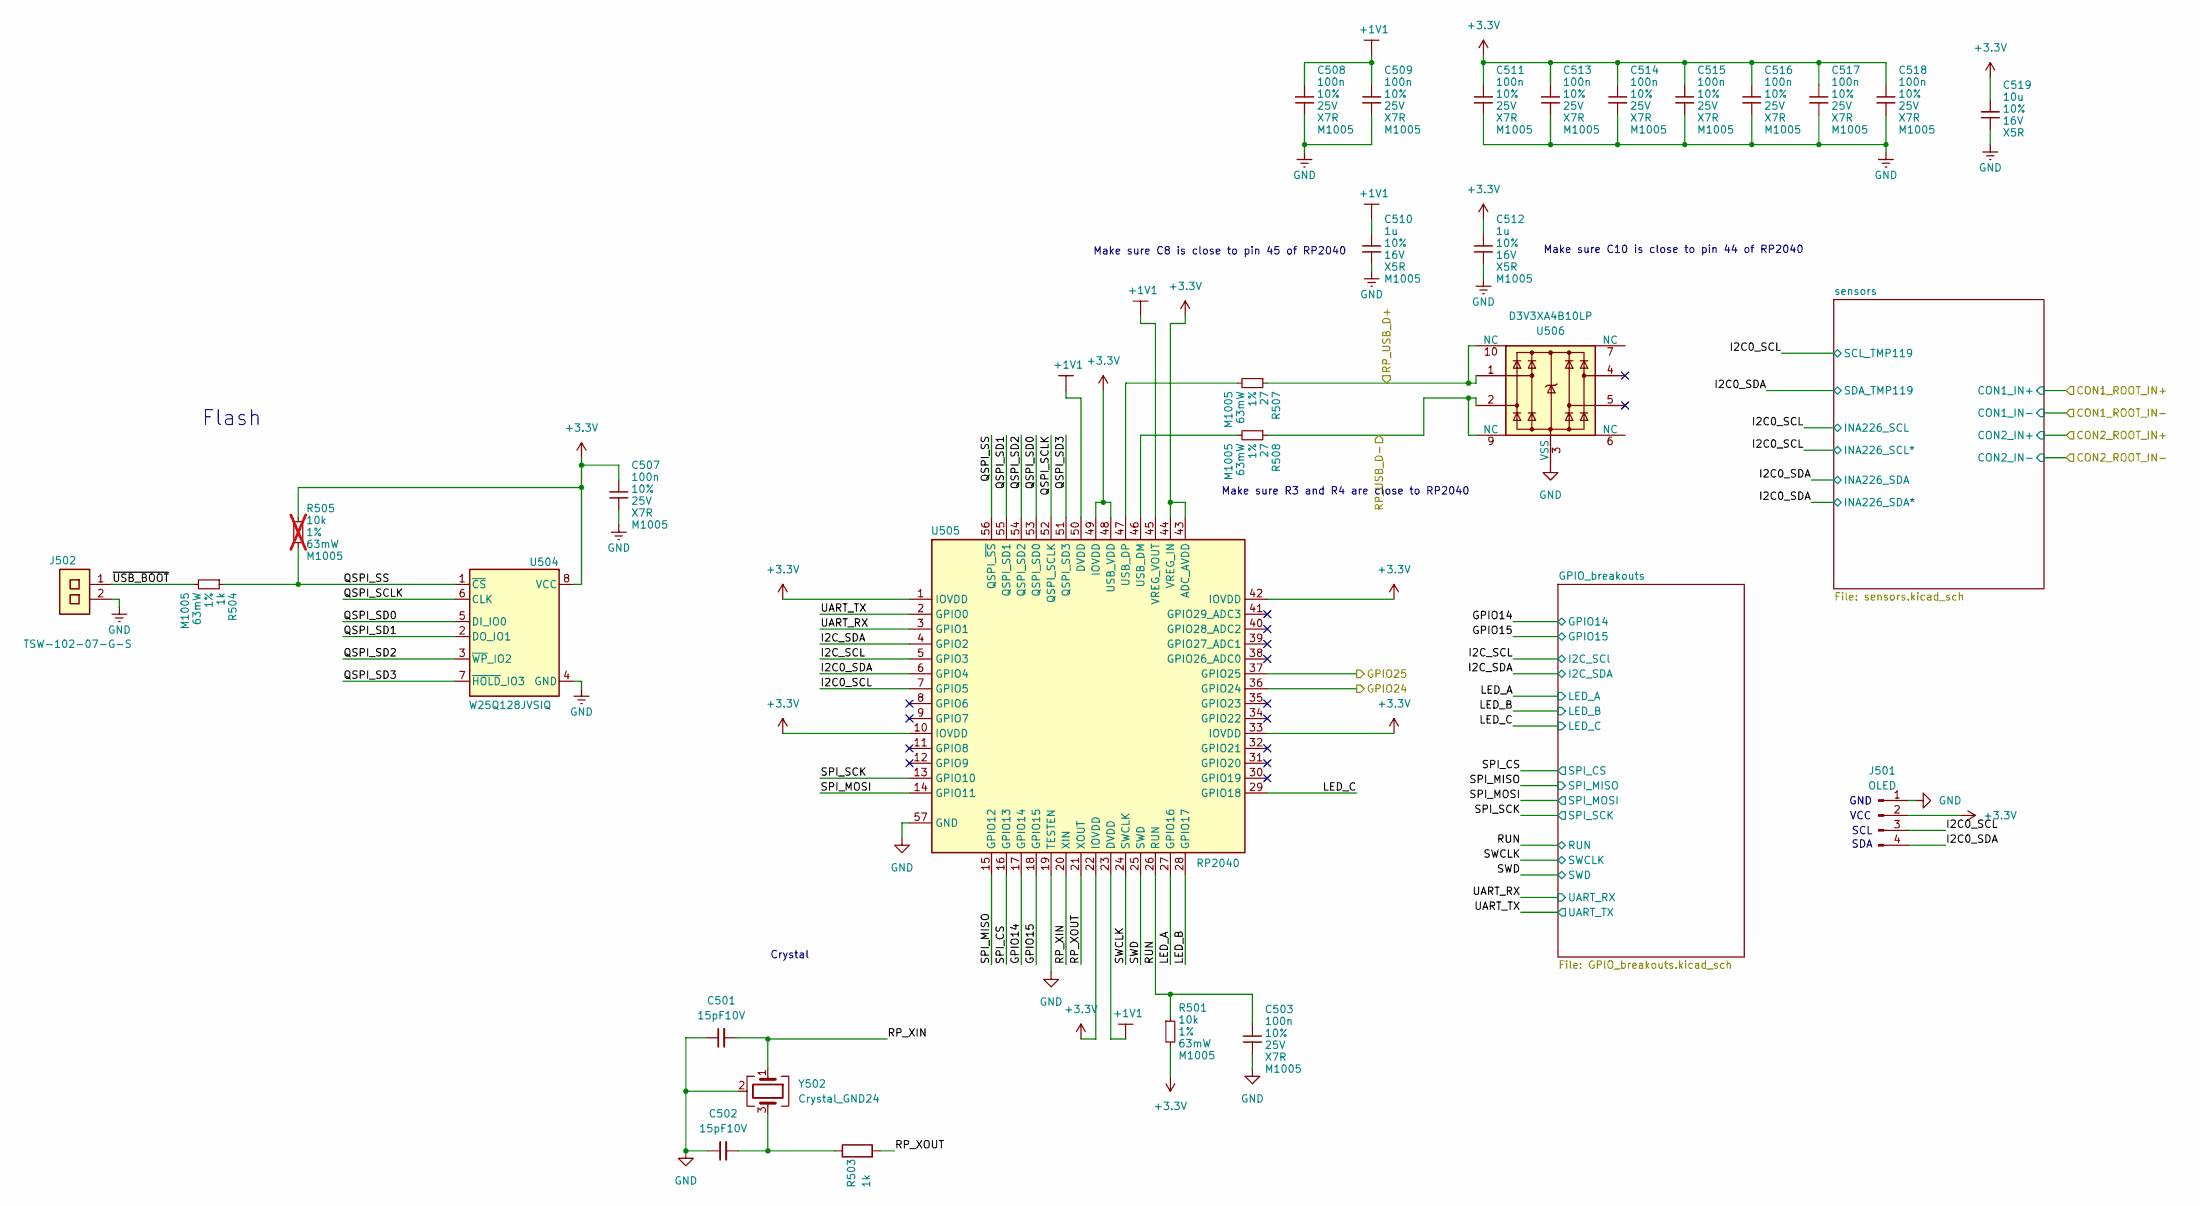
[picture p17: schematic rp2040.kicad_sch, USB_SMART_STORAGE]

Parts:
C501, C502: 15pF10V; C_0402_1005Metric
C503, C507, C508, C509, C511, C513, C514, C515, C516, C517, C518: 100n; C_0402_1005Metric; voltage 25V; tolerance 10%; part_uid RP-01BJ9Y-KRGF41
C510, C512: 1u; C_0603_1608Metric; voltage 16V; tolerance 10%; part_uid RP-01GYSK-L7FEKV
C519: 10u; C_0603_1608Metric; voltage 16V; tolerance 10%; part_uid RP-01GYSK-AVBE41
J501: OLED; PinHeader_1x04_P2.54mm_Vertical
J502: TSW-102-07-G-S; TE_440054-2_1x02_P2.00mm_Vertical; part_uid RP-01JV5X-LY21H5
R501: 10k; R_0402_1005Metric; tolerance 1%; voltage 50V; part_uid RP-019A1P-53DHSX
R503: 1k; R_0402_1005Metric
R504: 1k; R_0402_1005Metric; tolerance 1%; voltage 50V; part_uid RP-019A1P-4Z6ZWY
R505: 10k; R_0402_1005Metric; tolerance 1%; voltage 50V; part_uid RP-019A1P-53DHSX; not fitted
R507, R508: 27; R_0402_1005Metric; tolerance 1%; voltage 50V; part_uid RP-01C89V-LTEYC4
U504: W25Q128JVSIQ; voltage 2.7-3.6V; part_uid RP-01JWD4-F1H4N9
U505: RP2040; QFN-56-1EP_7x7mm_P0.4mm_EP3.2x3.2mm; part_uid RP-01EKHS-ZTKTEH
U506: D3V3XA4B10LP; Diodes_UDFN-10_1x2.5mm_P0.5mm
Y502: Crystal_GND24; Crystal_SMD_Abracon_ABM8G-4Pin_3.2x2.5mm

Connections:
+1V1: C508.1, C509.1, C510.1, U505.23 (DVDD), U505.45 (VREG_VOUT), U505.50 (DVDD)
+3.3V: C507.1, C511.1, C512.1, C513.1, C514.1, C515.1, C516.1, C517.1, C518.1, C519.1, J501.2, R501.2, R505.1, U504.8 (VCC), U505.1 (IOVDD), U505.10 (IOVDD), U505.22 (IOVDD), U505.33 (IOVDD), U505.42 (IOVDD), U505.43 (ADC_AVDD), U505.44 (VREG_IN), U505.48 (USB_VDD), U505.49 (IOVDD); also elsewhere on the board
/ORING_POWER/NOTIFY_3V3_Con1: U505.36 (GPIO24); also elsewhere on the board
/ORING_POWER/NOTIFY_3V3_Con2: U505.37 (GPIO25); also elsewhere on the board
/RP2040/GPIO14: U505.17 (GPIO14); also elsewhere on the board
/RP2040/GPIO15: U505.18 (GPIO15); also elsewhere on the board
/RP2040/I2C0_SCL: J501.3, U505.7 (GPIO5); also elsewhere on the board
/RP2040/I2C0_SDA: J501.4, U505.6 (GPIO4); also elsewhere on the board
/RP2040/I2C_SCL: U505.5 (GPIO3); also elsewhere on the board
/RP2040/I2C_SDA: U505.4 (GPIO2); also elsewhere on the board
/RP2040/LED_A: U505.27 (GPIO16); also elsewhere on the board
/RP2040/LED_B: U505.28 (GPIO17); also elsewhere on the board
/RP2040/LED_C: U505.29 (GPIO18); also elsewhere on the board
/RP2040/QSPI_SCLK: U504.6 (CLK), U505.52 (QSPI_SCLK)
/RP2040/QSPI_SD0: U504.5 (DI_IO0), U505.53 (QSPI_SD0)
/RP2040/QSPI_SD1: U504.2 (DO_IO1), U505.55 (QSPI_SD1)
/RP2040/QSPI_SD2: U504.3 (~WP_IO2), U505.54 (QSPI_SD2)
/RP2040/QSPI_SD3: U504.7 (~HOLD_IO3), U505.51 (QSPI_SD3)
/RP2040/QSPI_SS: R504.1, R505.2, U504.1 (~CS), U505.56 (QSPI_~SS)
/RP2040/RP_USB_D+: R507.1, U506.1, U506.10 (NC); also elsewhere on the board
/RP2040/RP_USB_D-: R508.1, U506.2, U506.9 (NC); also elsewhere on the board
/RP2040/RP_XIN: C501.2, U505.20 (XIN), Y502.1
/RP2040/RP_XOUT: R503.2, U505.21 (XOUT)
/RP2040/RUN: C503.1, R501.1, U505.26 (RUN); also elsewhere on the board
/RP2040/SPI_CS: U505.16 (GPIO13); also elsewhere on the board
/RP2040/SPI_MISO: U505.15 (GPIO12); also elsewhere on the board
/RP2040/SPI_MOSI: U505.14 (GPIO11); also elsewhere on the board
/RP2040/SPI_SCK: U505.13 (GPIO10); also elsewhere on the board
/RP2040/SWCLK: U505.24 (SWCLK); also elsewhere on the board
/RP2040/SWD: U505.25 (SWD); also elsewhere on the board
/RP2040/UART_RX: U505.3 (GPIO1); also elsewhere on the board
/RP2040/UART_TX: U505.2 (GPIO0); also elsewhere on the board
/RP2040/~USB_BOOT: J502.1, R504.2
GND: C501.1, C502.1, C503.2, C507.2, C508.2, C509.2, C510.2, C511.2, C512.2, C513.2, C514.2, C515.2, C516.2, C517.2, C518.2, C519.2, J501.1, J502.2, U504.4 (GND), U505.19 (TESTEN), U505.57 (GND), U506.3 (VSS), U506.8 (VSS), Y502.2 (G), Y502.4 (G); also elsewhere on the board
unnamed: C502.2, R503.1, Y502.3
unnamed: R508.2, U505.46 (USB_DM)
unnamed: R507.2, U505.47 (USB_DP)

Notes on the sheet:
Flash
SDA
Make sure C10 is close to pin 44 of RP2040
VCC
Crystal
Make sure C8 is close to pin 45 of RP2040
Make sure R3 and R4 are close to RP2040
SCL
GND

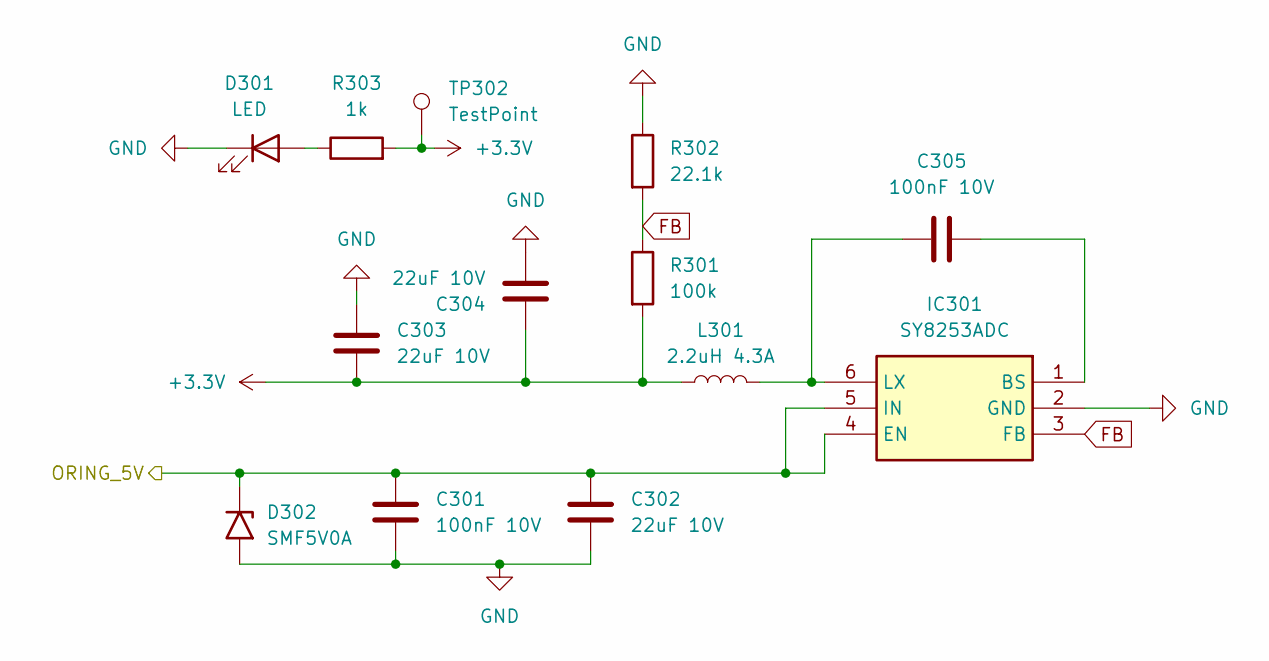
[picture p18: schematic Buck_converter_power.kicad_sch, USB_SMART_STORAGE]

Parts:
C301, C305: 100nF 10V; C_0402_1005Metric
C302, C303, C304: 22uF 10V; C_0805_2012Metric
D301: LED; LED_0603_1608Metric
D302: SMF5V0A; D_SMF
IC301: SY8253ADC; SOT95P285X100-6N; Manufacturer_Part_Number SY8253ADC
L301: 2.2uH 4.3A; L_Sunlord_SWPA4020S
R301: 100k; R_0402_1005Metric
R302: 22.1k; R_0402_1005Metric
R303: 1k; R_0402_1005Metric
TP302: TestPoint; TestPoint_Pad_D1.5mm

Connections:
+3.3V: C303.2, C304.1, L301.1, R301.2, R303.2, TP302.1 (1_1); also elsewhere on the board
/ORING_POWER/ORING_5V: C301.1, C302.1, D302.1 (A1), IC301.4 (EN), IC301.5 (IN); also elsewhere on the board
FB: IC301.3 (FB), R301.1, R302.2
GND: C301.2, C302.2, C303.1, C304.2, D301.1 (K), D302.2 (A2), IC301.2 (GND), R302.1; also elsewhere on the board
unnamed: D301.2 (A), R303.1
unnamed: C305.2, IC301.1 (BS)
unnamed: C305.1, IC301.6 (LX), L301.2

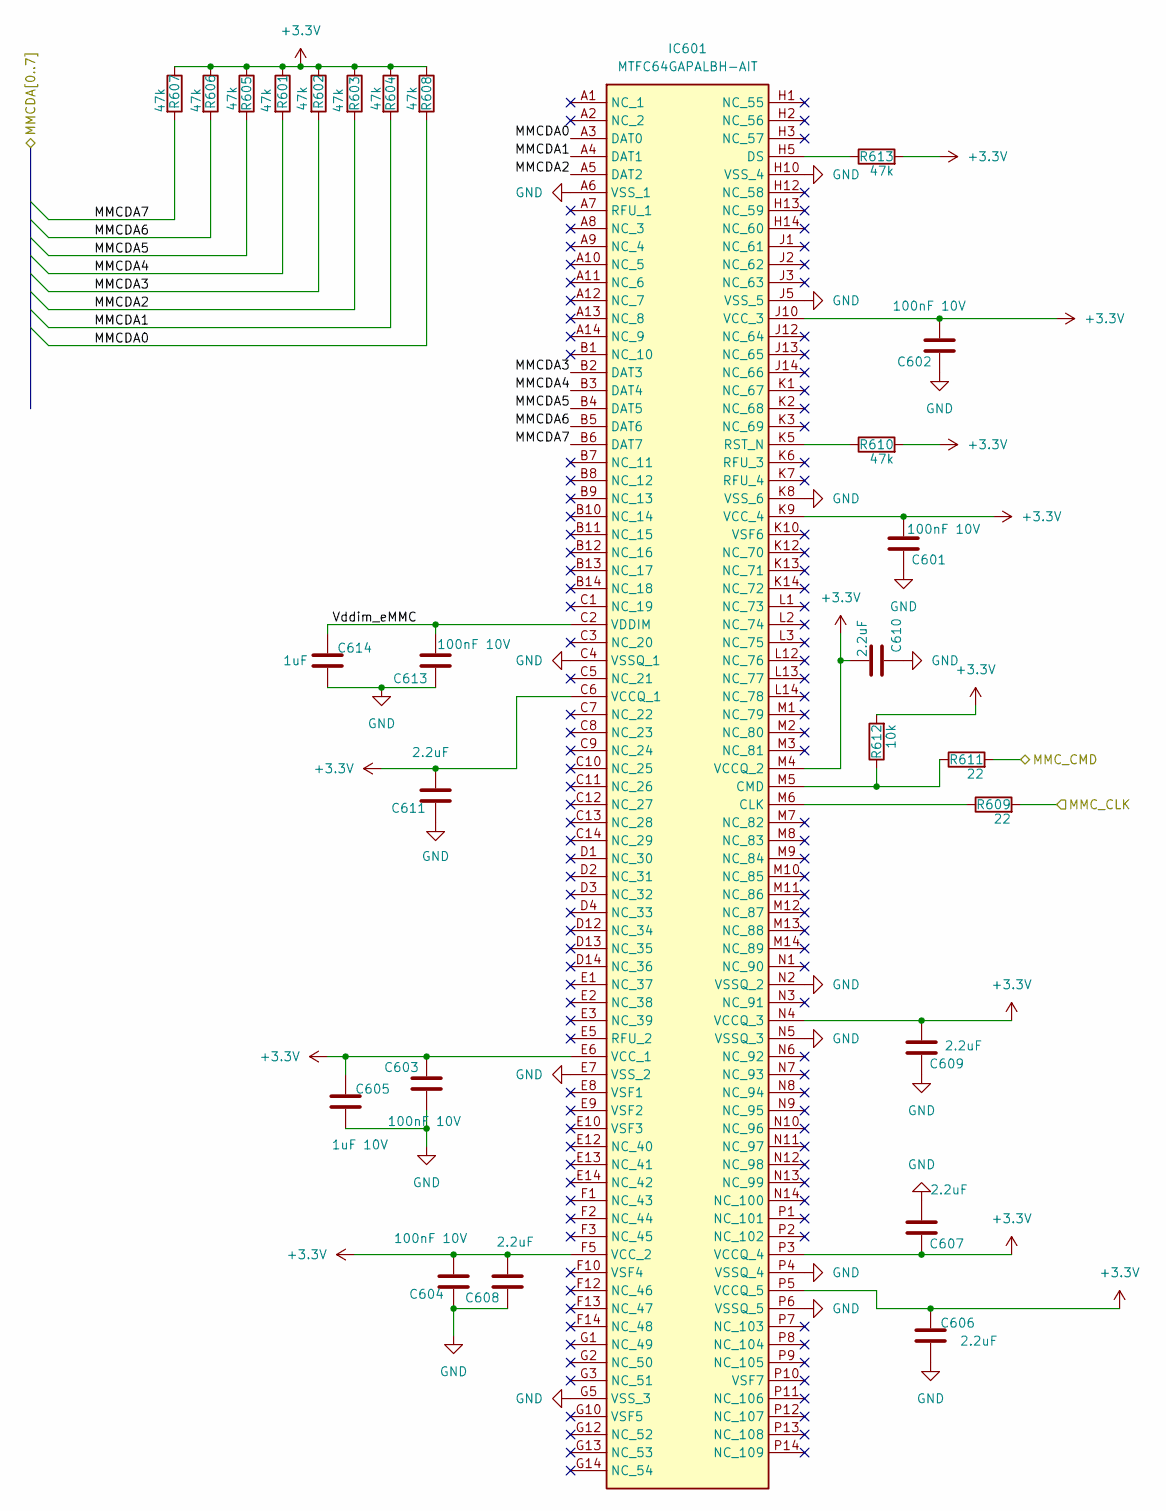
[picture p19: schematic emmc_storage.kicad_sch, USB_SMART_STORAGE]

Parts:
C601, C602, C603, C604, C613: 100nF 10V; C_0402_1005Metric
C605: 1uF 10V; C_0402_1005Metric
C606, C607, C608, C609, C610, C611: 2.2uF; C_0402_1005Metric
C614: 1uF; C_0402_1005Metric
IC601: MTFC64GAPALBH-AIT; Manufacturer_Part_Number MTFC64GAPALBH-AIT; Mouser Part Number 340-349211-TRAY
R601, R602, R603, R604, R605, R606, R607, R608, R610, R613: 47k; R_0402_1005Metric
R609, R611: 22; R_0402_1005Metric
R612: 10k; R_0402_1005Metric

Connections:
+3.3V: C601.1, C602.1, C603.2, C604.1, C605.2, C606.2, C607.2, C608.1, C609.1, C610.1, C611.1, IC601.C6 (VCCQ_1), IC601.E6 (VCC_1), IC601.F5 (VCC_2), IC601.J10 (VCC_3), IC601.K9 (VCC_4), IC601.M4 (VCCQ_2), IC601.N4 (VCCQ_3), IC601.P3 (VCCQ_4), IC601.P5 (VCCQ_5), R601.1, R602.1, R603.1, R604.1, R605.1, R606.1, R607.1, R608.1, R610.2, R612.2, R613.2; also elsewhere on the board
/EMMC_STORAGE/MMCDA0: IC601.A3 (DAT0), R608.2; also elsewhere on the board
/EMMC_STORAGE/MMCDA1: IC601.A4 (DAT1), R604.2; also elsewhere on the board
/EMMC_STORAGE/MMCDA2: IC601.A5 (DAT2), R603.2; also elsewhere on the board
/EMMC_STORAGE/MMCDA3: IC601.B2 (DAT3), R602.2; also elsewhere on the board
/EMMC_STORAGE/MMCDA4: IC601.B3 (DAT4), R601.2; also elsewhere on the board
/EMMC_STORAGE/MMCDA5: IC601.B4 (DAT5), R605.2; also elsewhere on the board
/EMMC_STORAGE/MMCDA6: IC601.B5 (DAT6), R606.2; also elsewhere on the board
/EMMC_STORAGE/MMCDA7: IC601.B6 (DAT7), R607.2; also elsewhere on the board
/EMMC_STORAGE/MMC_CLK: R609.2; also elsewhere on the board
/EMMC_STORAGE/MMC_CMD: R611.2; also elsewhere on the board
/EMMC_STORAGE/Vddim_eMMC: C613.1, C614.2, IC601.C2 (VDDIM)
GND: C601.2, C602.2, C603.1, C604.2, C605.1, C606.1, C607.1, C608.2, C609.2, C610.2, C611.2, C613.2, C614.1, IC601.A6 (VSS_1), IC601.C4 (VSSQ_1), IC601.E7 (VSS_2), IC601.G5 (VSS_3), IC601.H10 (VSS_4), IC601.J5 (VSS_5), IC601.K8 (VSS_6), IC601.N2 (VSSQ_2), IC601.N5 (VSSQ_3), IC601.P4 (VSSQ_4), IC601.P6 (VSSQ_5); also elsewhere on the board
unnamed: IC601.M6 (CLK), R609.1
unnamed: IC601.M5 (CMD), R611.1, R612.1
unnamed: IC601.H5 (DS), R613.1
unnamed: IC601.K5 (RST_N), R610.1

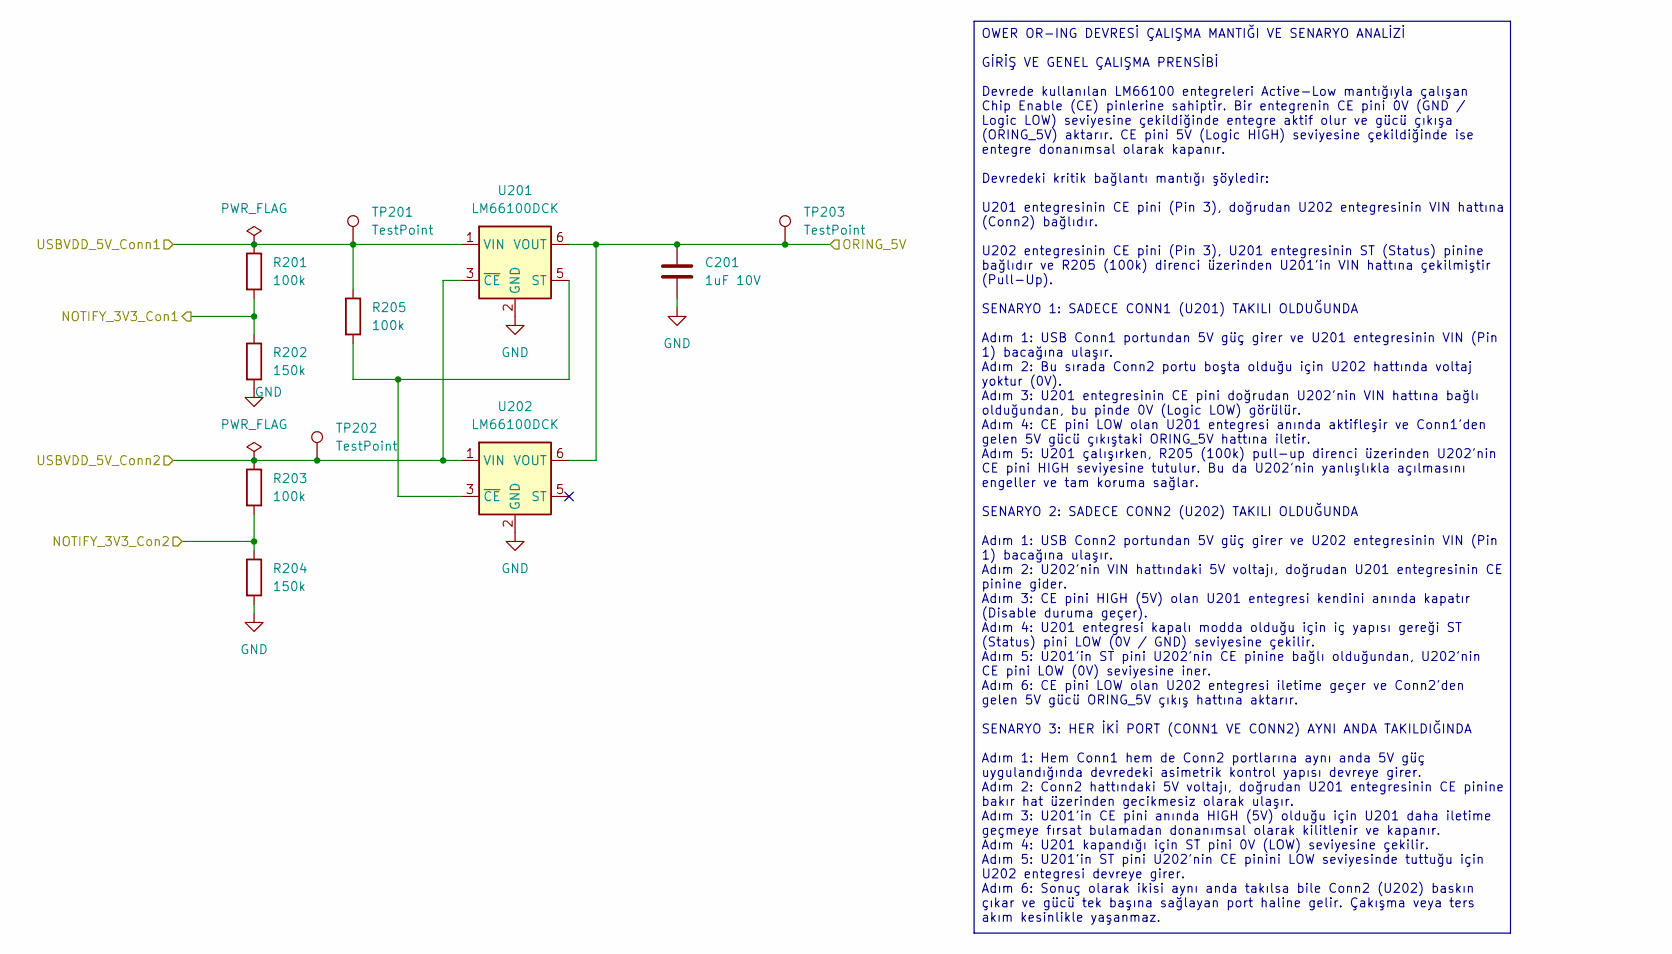
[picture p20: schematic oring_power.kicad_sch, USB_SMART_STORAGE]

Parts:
C201: 1uF 10V; C_0603_1608Metric
R201, R203, R205: 100k; R_0402_1005Metric
R202, R204: 150k; R_0402_1005Metric
TP201, TP202, TP203: TestPoint; TestPoint_Pad_D1.5mm
U201, U202: LM66100DCK; SOT-363_SC-70-6

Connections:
/ORING_POWER/NOTIFY_3V3_Con1: R201.2, R202.1; also elsewhere on the board
/ORING_POWER/NOTIFY_3V3_Con2: R203.2, R204.1; also elsewhere on the board
/ORING_POWER/ORING_5V: C201.1, TP203.1 (1_1), U201.6 (VOUT), U202.6 (VOUT); also elsewhere on the board
/VBUS_MCU: R203.1, TP202.1 (1_1), U201.3 (~CE), U202.1 (VIN); also elsewhere on the board
/VBUS_STORAGE: R201.1, R205.1, TP201.1 (1_1), U201.1 (VIN); also elsewhere on the board
GND: C201.2, R202.2, R204.2, U201.2 (GND), U202.2 (GND); also elsewhere on the board
unnamed: R205.2, U201.5 (ST), U202.3 (~CE)

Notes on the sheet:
OWER OR-ING DEVRESİ ÇALIŞMA MANTIĞI VE SENARYO ANALİZİ GİRİŞ VE GENEL ÇALIŞMA PRENSİBİ Devrede kullanılan LM66100 entegreleri Active-Low mantığıyla çalışan Chip Enable (CE) pinlerine sahiptir. Bir entegrenin CE pini 0V (GND / Logic LOW) seviyesine çekildiğinde entegre aktif olur ve gücü çıkışa (ORI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

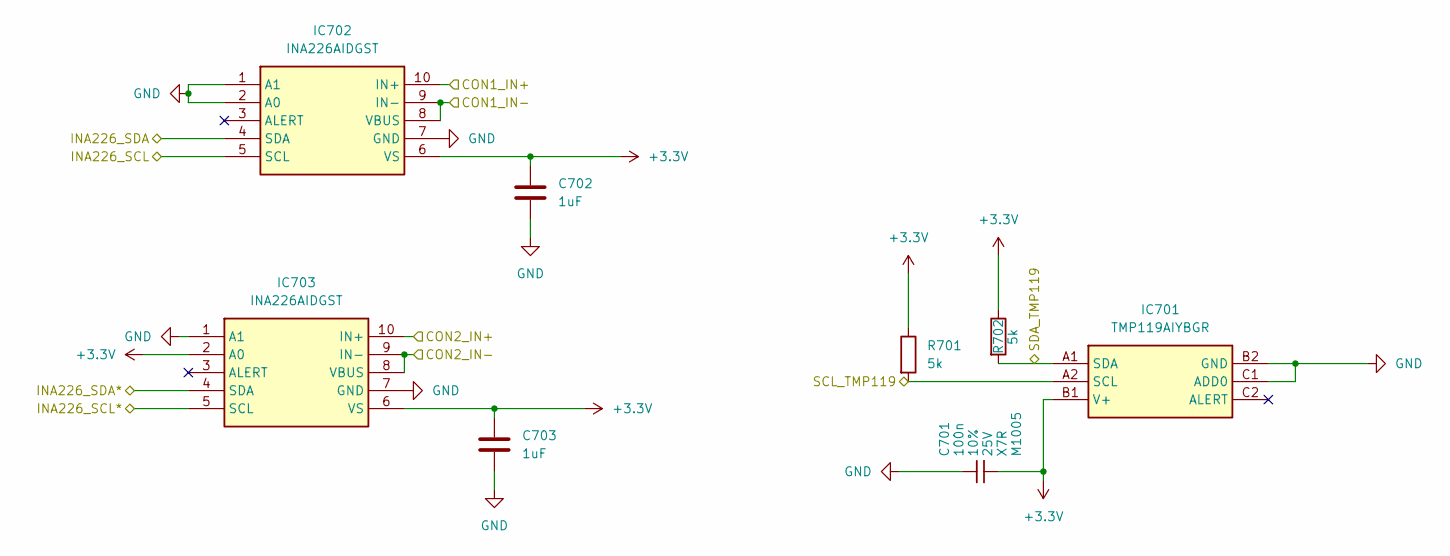
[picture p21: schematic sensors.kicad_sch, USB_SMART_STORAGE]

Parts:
C701: 100n; C_0402_1005Metric; voltage 25V; tolerance 10%; part_uid RP-01BJ9Y-KRGF41
C702: 1uF; C_0402_1005Metric
C703: 1uF; C_0603_1608Metric
IC701: TMP119AIYBGR; BGA6C40P2X3_95X149X52; Manufacturer_Part_Number TMP119AIYBGR; Mouser Part Number 595-TMP119AIYBGR
IC702, IC703: INA226AIDGST; SOP50P490X110-10N; Manufacturer_Part_Number INA226AIDGST; Mouser Part Number 595-INA226AIDGST
R701, R702: 5k; R_0402_1005Metric

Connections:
+3.3V: C701.2, C702.1, C703.1, IC701.B1 (V+), IC702.6 (VS), IC703.2 (A0), IC703.6 (VS), R701.1, R702.1; also elsewhere on the board
/RP2040/I2C0_SCL: IC701.A2 (SCL), IC702.5 (SCL), IC703.5 (SCL), R701.2; also elsewhere on the board
/RP2040/I2C0_SDA: IC701.A1 (SDA), IC702.4 (SDA), IC703.4 (SDA), R702.2; also elsewhere on the board
/VBUS_MCU__IN+: IC703.10 (IN+); also elsewhere on the board
/VBUS_MCU__IN-: IC703.8 (VBUS), IC703.9 (IN-); also elsewhere on the board
/VBUS_STORAGE_IN+: IC702.10 (IN+); also elsewhere on the board
/VBUS_STORAGE_IN-: IC702.8 (VBUS), IC702.9 (IN-); also elsewhere on the board
GND: C701.1, C702.2, C703.2, IC701.B2 (GND), IC701.C1 (ADD0), IC702.1 (A1), IC702.2 (A0), IC702.7 (GND), IC703.1 (A1), IC703.7 (GND); also elsewhere on the board

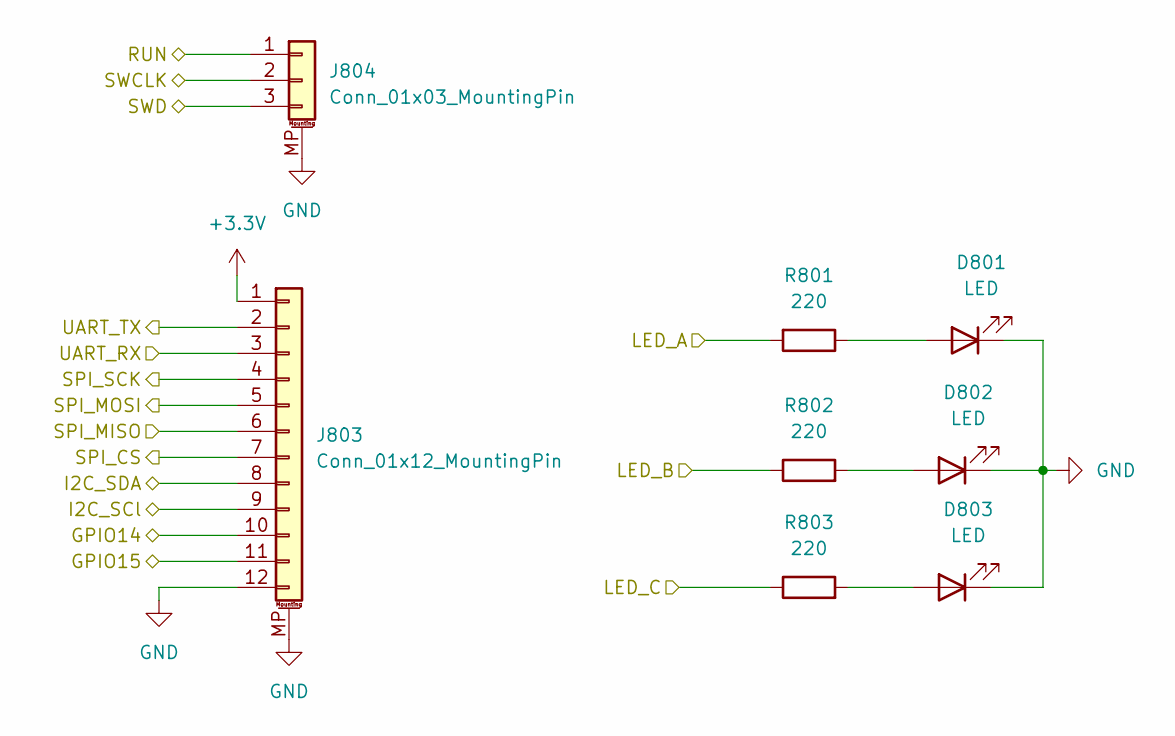
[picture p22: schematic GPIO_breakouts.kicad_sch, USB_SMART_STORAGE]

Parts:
D801, D802, D803: LED; LED_0603_1608Metric
J803: Conn_01x12_MountingPin; JST_SH_SM12B-SRSS-TB_1x12-1MP_P1.00mm_Horizontal
J804: Conn_01x03_MountingPin; JST_GH_SM03B-GHS-TB_1x03-1MP_P1.25mm_Horizontal
R801, R802, R803: 220; R_0402_1005Metric

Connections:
+3.3V: J803.1; also elsewhere on the board
/RP2040/GPIO14: J803.10; also elsewhere on the board
/RP2040/GPIO15: J803.11; also elsewhere on the board
/RP2040/I2C_SCL: J803.9; also elsewhere on the board
/RP2040/I2C_SDA: J803.8; also elsewhere on the board
/RP2040/LED_A: R801.2; also elsewhere on the board
/RP2040/LED_B: R802.1; also elsewhere on the board
/RP2040/LED_C: R803.1; also elsewhere on the board
/RP2040/RUN: J804.1; also elsewhere on the board
/RP2040/SPI_CS: J803.7; also elsewhere on the board
/RP2040/SPI_MISO: J803.6; also elsewhere on the board
/RP2040/SPI_MOSI: J803.5; also elsewhere on the board
/RP2040/SPI_SCK: J803.4; also elsewhere on the board
/RP2040/SWCLK: J804.2; also elsewhere on the board
/RP2040/SWD: J804.3; also elsewhere on the board
/RP2040/UART_RX: J803.3; also elsewhere on the board
/RP2040/UART_TX: J803.2; also elsewhere on the board
GND: D801.1 (K), D802.1 (K), D803.1 (K), J803.12, J803.MP (MountPin), J804.MP (MountPin); also elsewhere on the board
unnamed: D801.2 (A), R801.1
unnamed: D802.2 (A), R802.2
unnamed: D803.2 (A), R803.2

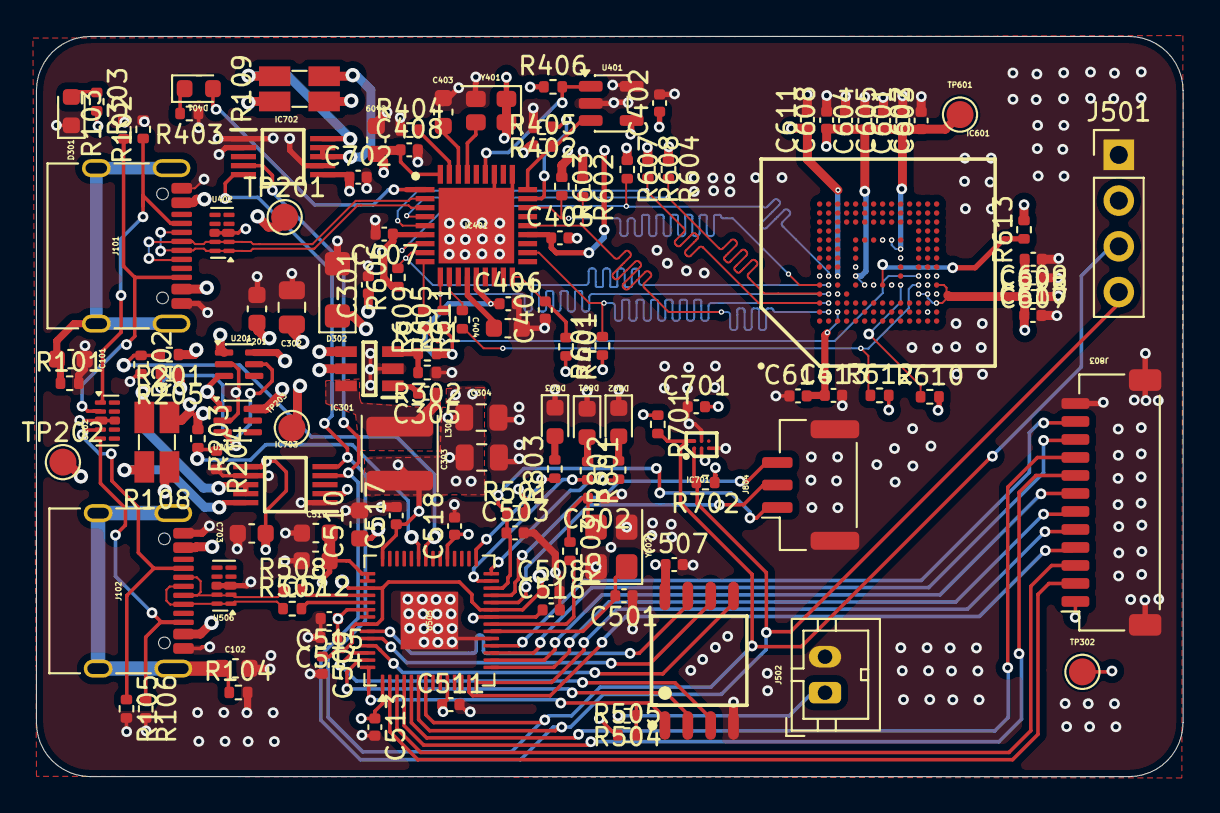
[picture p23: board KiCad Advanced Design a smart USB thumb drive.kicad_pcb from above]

Board: 4 copper layers, 63.7 x 41.1 mm, 133 parts (0 on the bottom side), 87 nets.

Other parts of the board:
TP601: TestPoint; TestPoint_Pad_D1.5mm

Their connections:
+3.3V: TP601.1 (1_1); also elsewhere on the board
